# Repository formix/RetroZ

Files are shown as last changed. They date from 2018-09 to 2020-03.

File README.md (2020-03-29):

# RetroZ SBC S80
A minimalist single board Z80 retro computer based on the S80 design 
specifications.

This board is developped using the S80 physical specifications. The 
specifications are not currently available online but I plan to fix that in a 
future revision.

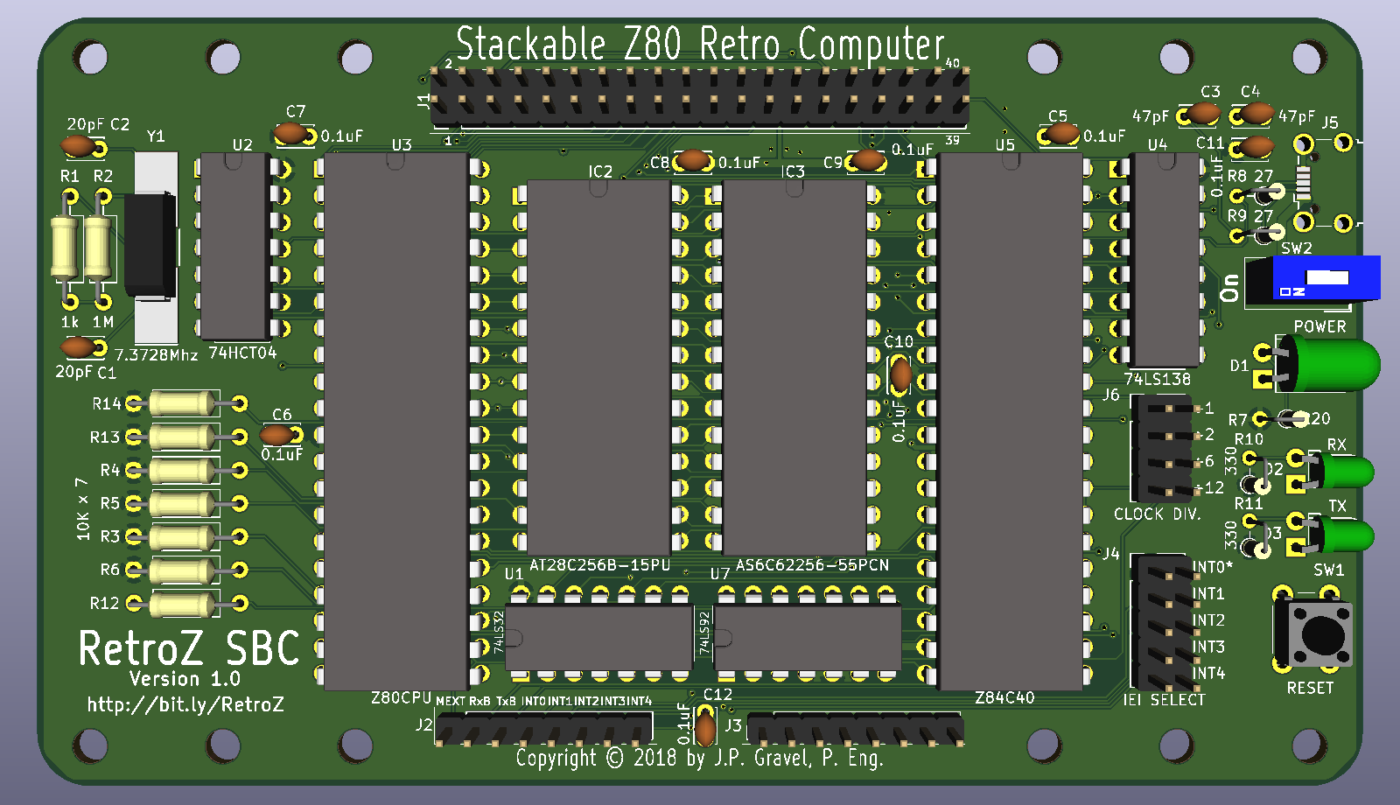
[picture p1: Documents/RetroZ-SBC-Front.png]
RetroZ SBC for S80 Architecture

*Front of the board*

[Back of the board](https://raw.githubusercontent.com/formix/RetroZ/master/Documents/RetroZ-SBC-Back.png)

You can find the board schematic as a PDF [here](https://github.com/formix/RetroZ/blob/master/Documents/RetroZ-SBC.pdf).

## BOM

You can download the BOM [here](https://github.com/formix/RetroZ/blob/master/Projects/RetroZ-SBC/RetroZ-SBC-BOM.ods?raw=true). It is an Open Document Worksheet file and you should be able to open it with Open/Libre Office or MS Excel. If you have issue, contact me.

| Comp. | Mouser#  | Digikey# | Mfr# | Qty | Description | 
|---|---|---|---|-----|---|
| C1,C2 | | | C317C200J5G5TA | 2 | 20pf Capacitor | 
| C3,C4 | | | FG28C0G1H470JNT06  | 2 | 47pF Capacitor | 
| C5,C6,C7,C8,C9,C10,C11,C12 | | | C322C104K5R5TA7301 | 8 | 0,1uF Capacitors | 
| D1 | | | 151051VS04000 | 1 | Green Led 5mm | 
| D2,D3 | | | 151031SS06000 | 2 | Red Led 3mm Round, FwdV 2.2 | 
| IC1 | | | ADM803TAKSZ-REEL7  | 1 | Power-on Reset chip | 
| IC2 | | | AT28C256-15PU | 1 | EEPROM 256kbit 28-Pin PDIP | 
| IC2,IC3 | | | 4828-6004-CP | 2 | CONN IC DIP SOCKET 28POS TIN | 
| IC3 | | | AS6C62256-55PCN | 1 | IC SRAM 256K PARALLEL 28DIP | 
| J1 | 485-2223 | 1528-1385-ND  | 2223 | 1 | Adafruit stacking header 2x20 | 
| J2,J3 | 485-85 | 1528-1074-ND  | 85 | 1 | STACKING HEADER ARDUINO SHIELD | 
| J4 | | | PRPC005DAAN-RC | 1 | 5x2 Pin Connector | 
| J4,J6 | | | QPC02SXGN-RC | 2 | 1x2 Shunt connector | 
| J5 | | | 629105150521 | 1 | USB Microb B SMT Connector | 
| J6 | | | PRPC004DAAN-RC | 1 | 4x2 Pin Connector | 
| R1 | | | RNF14FTD1M00 | 1 | 1M Ohm Resistor | 
| R10,R11 | | | RNF14FTD332R | 2 | 332 Ohm resistor | 
| R2 | | | RNF14FTD1K00 | 1 | 1k Ohm Resistor | 
| R3,R4,R5,R6,R12,R13,R14 | | | RNF14FTD10K0 | 7 | 10k Ohm Resistor | 
| R7 | | | RNF14FTD221R | 1 | 221 Ohm Resistor | 
| R8,R9 | | | RNF14FTD27R4 | 2 | 27 Ohm Resistors | 
| SW2 | | | BD01 | 1 | DIP Switch x1 | 
| U1 | | | 74LS32 | 1 | Quand OR | 
| U2 | | | 74HCT04 | 1 | Hex Inverter Schmidt Trigger | 
| U3 | | | Z84C0008PEG | 1 | Z80 CPU | 
| U3,U5 | | | 4840-6004-CP | 1 | 40 pin (2 x 20) DIP socket 15,24mm | 
| U4 | | | SN74LS138N | 1 | 3 to 8 Decoder/Demux | 
| U5 | | | Z84C4208PEG | 1 | Z80 SIO/2 | 
| U6 | | | FT230XS-U | 1 | UART to USB | 
| U7 | | | 74LS92 | 1 | Dodecade counter (div. By 12) | 
| Y1 | | | ECS-73-20-5PX-TR | 1 | 7,3728 MHz Crystal | 

## Development Note

### 2019-01-15
The review phase is done! I just sent the board to production. I should get the
finished board next week.

### 2019-01-26
I recieved my boards (10 boards!) yesterday. I just finished creating the BOM 
and sorted through my parts to order what is missing. I expect to recieve my 
order in the coming week. I'll work on the NASCOM Basic once I got the 
computer assembled. Stay tuned!

### 2019-08-03
It's been a while since I updated that README file but as you can see,
I'm committing regularily on the project. Simply put, I'm too busy playing 
with my working RetroZ SBC computer to update the front documentation. It is 
time to fix that, continue reading to get the full update.

## What's Inside?
The RetroZ-SBC computer is a 8MHz Z80 CPU clocked at 7.3728 MHz. It supports 
up to 32kB of ROM and 32kB of RAM. An SIO/2 chip is connected to the USB 
Micro B socket using an FTDI serial converter. Rx and Tx leds let you know 
when the computer communicates over USB. The whole computer is powered through
the same USB port and a power-on reset monitor resets the computer at startup.
A Reset button allows warm computer restart. An On/Off DIP switch controls the
power state of the computer and a power led indicator let you know that the 
beast is powered. All the Z80 processor pins are available through the 40 pins
stacking header plus some other on the User Port A. User Port B stacking
header is fully available (8 pins) for child boards future projects.

## The Connection
The USB to serial conversion is made possible thanks to an FTDI chip 
[behind the board](https://raw.githubusercontent.com/formix/RetroZ/master/Documents/RetroZ-SBC-Back.png) 
and is clocked at 115200 bauds by default. This speed can be changed 
programmatically through the Z84C40 (Zilog SIO/2) registers. On a Windows
machine the device can be accessed using **COM5**. For a 
Mac/Linux box it is **/dev/ttyUSB0**. Hardware flow control CTS/RTS is fully 
wired so feel free to flood the console with whatever you get, it should 
handle it.

## Technical Reference
### Power and commnunication over USB
Using a single USB Micro-B wire, it is possible to power-up and communicate 
with the computer. There is a DIP switch to set the computer on or off and a 
power indicator led indicates when the computer is powered on. There is also
a power line monitor chip (IC1) that pull the /RESET line LOW for 240 ms 
after power on.

### Serial Communication
Serial communication is achieved using a Z84C42 SIO/2 chip. The serial port A 
is connected to the USB jack through an FTDI UART to USB 2.0 converter. Rx 
and Tx leds indicate when communication occurs on that port. The serial port 
B is connected back into the User Port A (J2) PIN 2 (RxB) and Pin 3 (TxB) for 
slave cards serial communications.

**The serial port A clock** is directly tied to the clock and can be changed 
programmatically from the SIO/2 registers. In the NASCOM Basic provided, it is 
set to 115200 by default.

**The serial port B clock** The default speed is set to 115200 bauds as well. 
Again, that speed can be programmatically changed. The serial clock on port B 
goes through a dodecade counter and can be further adjusted using the 
`Clock div.` (J6) jumper that offers another set of 1,2,6 and 12 dividers. 
That gives a wide variety of standard baud rates down to 9600 bauds.

### Onboard memory control
The PIN 1 of the User Port A is pulled low with a 2k resistor. This is the 
on-board memory enable input pin (/ME). To disable onboard memory, an 
expansion card can set that pin HIGH. This would be the case with a memory 
expansion board. It can be hardwired to 5V to disable the onboard memory 
completely or it can be tied to some logic to leverage the on-board memory as 
needed.

### Interrupt Chaining
The RetroZ SBC design allows chaining interrupts of up to 4 slave boards. The
onboard SIO/2 IEO pin is hardwired to the User Port A INT0 (PIN 4). Its 
Interrupt Enable In pin can be tied to any of the other INT pins using the 
IEI Select jumper (J4). Selecting the first position of that jumper (INT0) 
sets the on-board SIO/2 as the Master. On slave boards, the Interrupt Enable 
In will have 6 positions. Also, a 4 positions IEO jumper header should be 
provided to select the right User Port A IEO position (pins 5-8). More on 
that on the slave board design document.

**WARNING** User Port A pins 4-8 (interrupts) are not protected. If you 
connect a daughter board without checking jumper settings first, you could 
short an IO pin on your stack and damage a chip! Looking into a solution to 
that in a future revision.

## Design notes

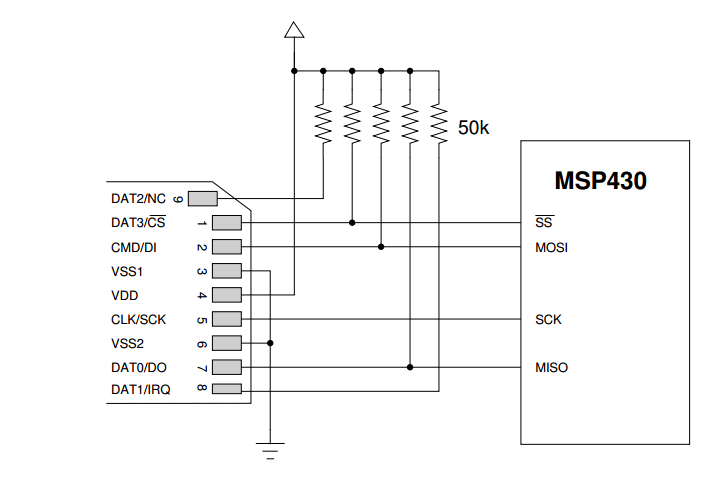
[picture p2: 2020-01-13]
Projects/RetroZ-disk/external-content.duckduckgo.com.png

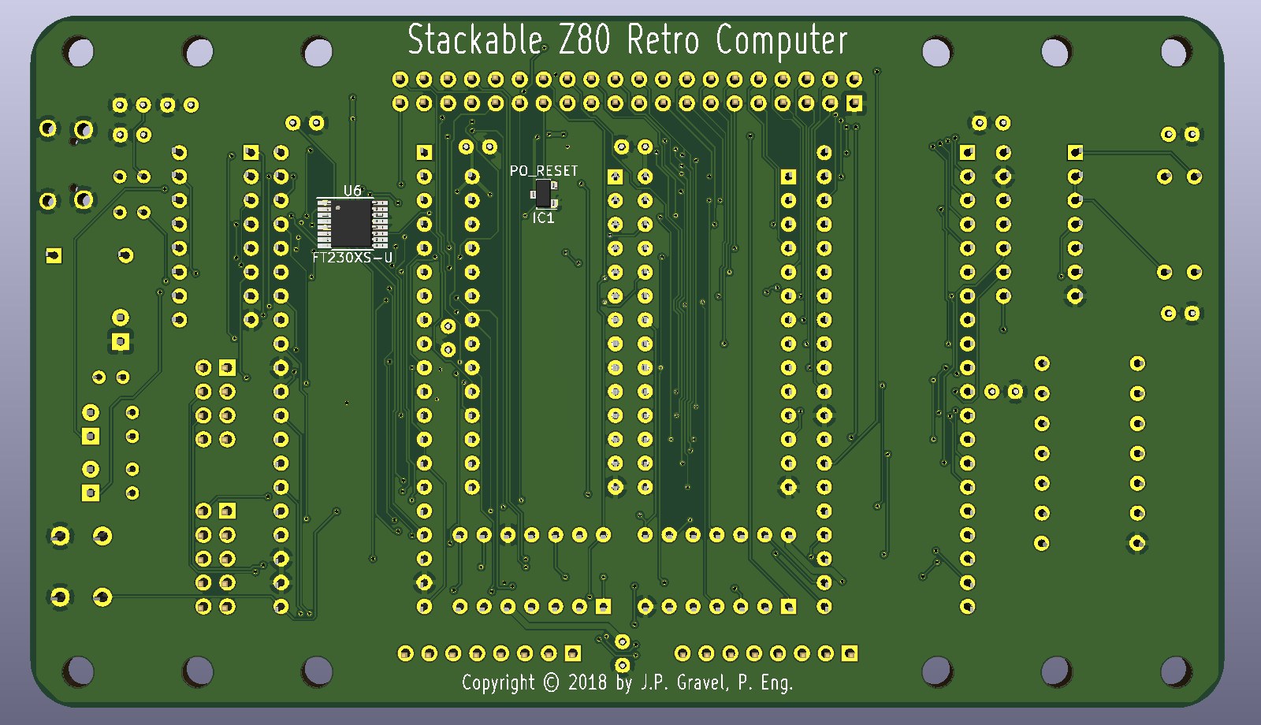
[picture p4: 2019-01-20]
Documents/RetroZ-SBC-Back.png

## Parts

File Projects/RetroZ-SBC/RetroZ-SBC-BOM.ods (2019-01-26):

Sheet: BOM
Comp. | Mouser# | Digikey# | Mfr# | Qty | Description | In stock | Mfr# | Order
C1,C2 |  |  | C317C200J5G5TA | 2 | 20pf Capacitor | 2 | C317C200J5G5TA | 0
C3,C4 |  |  | FG28C0G1H470JNT06 | 2 | 47pF Capacitor | 2 | FG28C0G1H470JNT06 | 0
C5,C6,C7,C8,C9,C10,C11,C12 |  |  | C322C104K5R5TA7301 | 8 | 0,1uF Capacitors | 0 | C322C104K5R5TA7301 | 8
D1 |  |  | 151051VS04000 | 1 | Green Led 5mm | 1 | 151051VS04000 | 0
D2,D3 |  |  | 151031SS06000 | 2 | Red Led 3mm Round, FwdV 2.2 | 2 | 151031SS06000 | 0
IC1 |  |  | ADM803TAKSZ-REEL7 | 1 | Power-on Reset chip | 1 | ADM803TAKSZ-REEL7 | 0
IC2 |  |  | AT28C256-15PU | 1 | EEPROM 256kbit 28-Pin PDIP | 0 | AT28C256-15PU | 1
IC2,IC3 |  |  | 4828-6004-CP | 2 | CONN IC DIP SOCKET 28POS TIN | 2 | 4828-6004-CP | 0
IC3 |  |  | AS6C62256-55PCN | 1 | IC SRAM 256K PARALLEL 28DIP | 0 | AS6C62256-55PCN | 1
J1 | 485-2223 | 1528-1385-ND | 2223 | 1 | Adafruit stacking header 2x20 | 1 | 1528-1385-ND | 0
J2,J3 | 485-85 | 1528-1074-ND | 85 | 1 | STACKING HEADER ARDUINO SHIELD | 0 | 1528-1074-ND | 1
J4 |  |  | PRPC005DAAN-RC | 1 | 5x2 Pin Connector | 0 | PRPC005DAAN-RC | 1
J4,J6 |  |  | QPC02SXGN-RC | 2 | 1x2 Shunt connector | 0 | QPC02SXGN-RC | 2
J5 |  |  | 629105150521 | 1 | USB Microb B SMT Connector | 1 | 629105150521 | 0
J6 |  |  | PRPC004DAAN-RC | 1 | 4x2 Pin Connector | 0 | PRPC004DAAN-RC | 1
R1 |  |  | RNF14FTD1M00 | 1 | 1M Ohm Resistor | 1 | RNF14FTD1M00 | 0
R10,R11 |  |  | RNF14FTD332R | 2 | 332 Ohm resistor | 0 | RNF14FTD332R | 2
R2 |  |  | RNF14FTD1K00 | 1 | 1k Ohm Resistor | 1 | RNF14FTD1K00 | 0
R3,R4,R5,R6,R12,R13,R14 |  |  | RNF14FTD10K0 | 7 | 10k Ohm Resistor | 7 | RNF14FTD10K0 | 0
R7 |  |  | RNF14FTD221R | 1 | 221 Ohm Resistor | 0 | RNF14FTD221R | 1
R8,R9 |  |  | RNF14FTD27R4 | 2 | 27 Ohm Resistors | 0 | RNF14FTD27R4 | 2
SW2 |  |  | BD01 | 1 | DIP Switch x1 | 1 | BD01 | 0
U1 |  |  | 74LS32 | 1 | Quand OR | 1 | 74LS32 | 0
U2 |  |  | 74HCT04 | 1 | Hex Inverter Schmidt Trigger | 1 | 74HCT04 | 0
U3 |  |  | Z84C0008PEG | 1 | Z80 CPU | 1 | Z84C0008PEG | 0
U3,U5 |  |  | 4840-6004-CP | 1 | 40 pin (2 x 20) DIP socket 15,24mm | 1 | 4840-6004-CP | 0
U4 |  |  | SN74LS138N | 1 | 3 to 8 Decoder/Demux | 1 | SN74LS138N | 0
U5 |  |  | Z84C4208PEG | 1 | Z80 SIO/2 | 1 | Z84C4208PEG | 0
U6 |  |  | FT230XS-U | 1 | UART to USB | 1 | FT230XS-U | 0
U7 |  |  | 74LS92 | 1 | Dodecade counter (div. By 12) | 1 | 74LS92 | 0
Y1 |  |  | ECS-73-20-5PX-TR | 1 | 7,3728 MHz Crystal | 1 | ECS-73-20-5PX-TR | 0

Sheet: Order
Mfr# | Order
RNF14FTD1M00 | 0
RNF14FTD1K00 | 0
74HCT04 | 0
ECS-73-20-5PX-TR | 0
C317C200J5G5TA | 0
ADM803TAKSZ-REEL7 | 0
FT230XS-U | 0
BD01 | 0
629105150521 | 0
RNF14FTD27R4 | 2 | 2,RNF14FTD27R4,
FG28C0G1H470JNT06 | 0
C322C104K5R5TA7301 | 8 | 8,C322C104K5R5TA7301,
151031SS06000 | 0
RNF14FTD332R | 2 | 2,RNF14FTD332R,
RNF14FTD10K0 | 0
74LS32 | 0
RNF14FTD221R | 1 | 1,RNF14FTD221R,
151051VS04000 | 0
74LS92 | 0
SN74LS138N | 0
PRPC004DAAN-RC | 1 | 1,PRPC004DAAN-RC,
PRPC005DAAN-RC | 1 | 1,PRPC005DAAN-RC,
QPC02SXGN-RC | 2 | 2,QPC02SXGN-RC,
1528-1385-ND | 0
1528-1074-ND | 1 | 1,1528-1074-ND,
Z84C0008PEG | 0
4840-6004-CP | 0
Z84C4208PEG | 0
AT28C256-15PU | 1 | 1,AT28C256-15PU,
AS6C62256-55PCN | 1 | 1,AS6C62256-55PCN,
4828-6004-CP | 0

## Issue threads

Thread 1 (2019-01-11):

General questions on design 2018-12-26

ghost, 2019-01-11:
Hi @formix,

First of all: _**great job**_! I like the schematic and the PCB even more. It's great that u use the Z80 SIO IC and that you join the schematics for UART to USB. The way you integrate your RetroZ with possible S80 extension cards is _**very well done and to my opinion flawless**_!

However, I have some minor questions.

# Schematics

### 1. Pull-down resistors

You don't pull down the -BusRq- pin of the CPU. Is there a special reason to keep it floating? I'm attentive to this element, since it's my major mistake on the design of the cpu board of the S80 Version 2.0 :-)

### 2. -Reset-

I'm a bit puzzled on the -Reset- circuit. The switch pulls it down to Gnd when pushed, and the resistor pulls it up by default. However, I don't see what IC1 is doing.

Is there a chance that your button will bounce and disturb the reset process of your RetroZ?

### 3. MEM_EXT

Please ignore my remark on pulling down the MEM_EXT pin in the S80 issue u've opened. You already do so (which I missed at my first reading of your schematics). Sorry for that.

### 4. SIO2_SEL generation

If I'm not mistaking, by using the 74xx138, you reserve all addresses of the format 111001xx (base address 0xE4). Is that correct?

### 5. USB

I'm I correct that you don't implement the UART to USB on your PCB?

# PCB

Is there a reason why u use males for the 2x20 connector on the top side of your PCB? The S80 uses the female side of the connectors on the top side and male connectors on the bottom side.

# Documentation on GitHub

I like your documentation very much. It's clear, extensive, and complete. If you ever feel the urge to document the S80 repository in the same way, please do not hesitate.

# Proposal

If you like, I can put your RetroZ-SBC repository (or a copy of the final version, the files that you choose) as a third party made S80 CPU/SERIAL/MEMORY card in a subdirectory of the S80/hardware. e.g. S80/Hardware/RetroZ-SBC. This can include documentation, libraries, your name and copyright notices, ...

Once you have software for your RetroZ, I can also put versions of your software in the S80/Software directory.

I like to copy in stead of linking, since that way, I prevent having dead links in the future, and I'm sure to have a stable version to distribute to the public.

# On the whole

Splendid job, respect !

formix, 2019-01-11:
Hi @PaintedBlck ,

First I'd like to thank you for taking some time to review my work, It is really appreciated!

So here are my asnwers:

#A: 1. Pull-down resistors
I totally forgot that one, thanks! But you mean a **pull-up** resistor right? based on the [RC2014 mini schematics](http://rc2014.co.uk/wp-content/uploads/2016/10/RC2014-Mini.pdf), I think both ~BUSREQ and ~BUSACK shall be pulled high. I'll fix that!

#A: 2. Reset
When [IC1](https://www.mouser.ca/ProductDetail/584-ADM803TAKSZ-R7) is powered, it pulls its PIN 2 LOW for 240ms then keep it HIGH. That's it. It is a power-on reset chip that saves a lot of space and some components. On the schematic, it is located left of the processor and it is connected on the bus. I think it would help to have it near the reset button and add some text next to it to make things clearer.

#A: 3. MEM_EXT
Ok, no issue then :).

#A: 4. SIO2_SEL generation
No, given the way the 74xx138 chip is connected, the reserved addresses are 0x00 to 0x03.

#A: 5. USB
The UART to USB is fully connected and working, based on my previous tests. The FT230XS chip is doing its magic and makes the board plung and play. Note that a USB port marked with a lightning should be used since these ports can deliver more amps (these are charger ports on the computer).

#A: PCB
Yeah, my note under the board's 3D view is wrong, I should have said TOP instead of BOTTOM. I'll fix that.

#A: Documentation on GitHub
Yeah, I'd be pleased to do that. I'll see where I can start and try to fit that in my schedule.

#A: Proposal
That would make sense but I'm still planning to change a few things before I send my board to production. You can do as you wish but I already plan to keep the repos open and images and PDFs where they are since that would break my documentation as well! I'll let you know when I update my things.

Thanks angain for your good words adn comments!

Closed 2019-09-08.

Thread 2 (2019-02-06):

The clock signal oscillate between 3v and 5v

formix, 2019-02-06:
Instead of oscillating between 0 and 5 vols, it oscillates between 3 and 5v. Nothing works with that.

formix, 2019-02-06:
After reviewing the board drawings, I saw that I inverted the 1M and 1K resistor label! I'llahave to replace the resistors and test again but I'm pretty sure it will be good.

formix, 2019-02-09:
Fixed, that was the issue!

Closed 2019-02-09.

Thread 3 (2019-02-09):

Unable to wake-up the SIO/2 chip

formix, 2019-02-09:
Hi all,

I need some help regarding my board. I'm not able to make the SIO/2 chip work. There is a chance that there is some physical issues I guess but I spent 3 months reviewing with some help from other people. For now, I would like to tackle this issues from the software angle.

First to make a quick and dirty 8k ROM, I slapped together Dr Scott M. Baker's ASM files for [SIO initialization](https://github.com/formix/rc2014/blob/master/asm/intsio.asm) and [8k Basic](https://github.com/formix/rc2014/blob/master/basic_work/scbasic/basdisk.asm). I fixed a few labels and changed SIOA_C, SIOA_D, SIOB_C and SIOB_D values to fit with my architecture (0x00, 0x01, 0x02 and 0x03 respectively). See my mashed-up file [here](https://github.com/formix/RetroZ/blob/master/asm/basic/sio_basic_32k.asm).

I expected that to be working but it's not doing anything. To make sure its is not related to my FTDI chip, I removed the SIO/2 chip and connected TX and RX together. The RX and TX leds are flashing with each letter I'm typing and I can see the "echo" in my terminal window.

I spent maybe two hours analyzing the SIO and BASIC asm code but I must admit that I'm still lost. I did slap the two files together within my [ASM source file](https://github.com/formix/RetroZ/blob/master/asm/basic/sio_basic_32k.asm) but it is basically what another shell script from @sbelectronics did (I can't find it anymore though). The `JP $0290` at the end of the first script and the `.ORG $0290` at the beginig of the second comforted me that It was ok like that. Other than a few lost clock cycles, I don't think that the CTC initialization stuff has anything to do with my issue.

I'm working in Ubuntu Bash with zasm.

One strange thing is that the generated ROM file has its instructions and operands inverted. For example, If I create an ASM file containing the following code:

```asm
  .ORG $0000
  LD A, 0
  .END
```
I'm expecting to see `3e00` (3e = `LD A`; 00 => the value `00`) in the resulting ROM file.

But what I see in the hexdump is this:
```hex
0000000 003e                           
0000002
```
The operand and the instruction are inverted!!! I was expecting to see big-endianess for 16 bits operands but not a flipped instruction! Why are the instruction and operand inverted? Is it an issue? Any idea what might be the overall problem here?

PaintedBlck, 2019-02-10:
To my knowledge, the Z80 is a big-ender, meaning that a 2-byte word (goes for instructions to) inverts its bytes to store them in memory (the same as the Intel 80x86 series do). So your hexdump is correct, since Zasm (and others) make a ROM that is 100% RAM compatible (immediately executable). Just storing things in it won't work.

On the other problem: have you tried to measure the pins of the SIO/2 with a logic analyser (I can advise e.g. the Kingst Logic Analyzer which does the trick for me). That way, you can measure some Z80 pins, some SIO/2 pins and see if the signals that have to arrive at the SIO/2 effectively arrive.

Grtz,
Filip

formix, 2019-02-11:
Thanks for your inputs @PaintedBlck!

You are right, I shall get back to the basics and make things simple. I tried to follow that path at first but I quickly switched to the "slap things together" when I found Dr S.M. Baker's code.

I do not have a logic analyzer, in fact I did not know that these things existed at all before you mentionned it. I was crudely debugging using a voltmeter and a barely working analog oscilloscope from the sixties.

I'll do what you suggest and update on my progress here.

formix, 2019-02-14:
I found out! I found out!!!!

The resistor R12 is a pull down.  but for some reason, the reading on it was around 1.9V instead of 0. This line being connected to the OR gate pin 2 to deactivate the RAM and ROM chips if the S80 "M/4M memory expansion board is present (it is also connected on the User port A, PIN 1).

**That 1.9V value is enough to turn the 74LS32N to HIGH, thus disabling the ROM's ~CE line!!!**

To check if I was right, I jumped that resistor and Bingo, I started to see the TX led flash like crazy and my terminal window being filled with X characters at the tremedeous speed of 115kb!!!!

The fix is to remove that resistor for now and jump it directly with a wire. I will double check but there is a good chance that changing that LS chip for an HCT will do the trick!!!

Man it feels great, that was my first hardware debugging!!!

Big thanks to @PaintedBlck  for you support and wisdom (I ordered a Kingst digital analyzer just yesterday) and to **Sylvain Beauregard**  for his good old oscilloscope!

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

Closed 2019-02-14.

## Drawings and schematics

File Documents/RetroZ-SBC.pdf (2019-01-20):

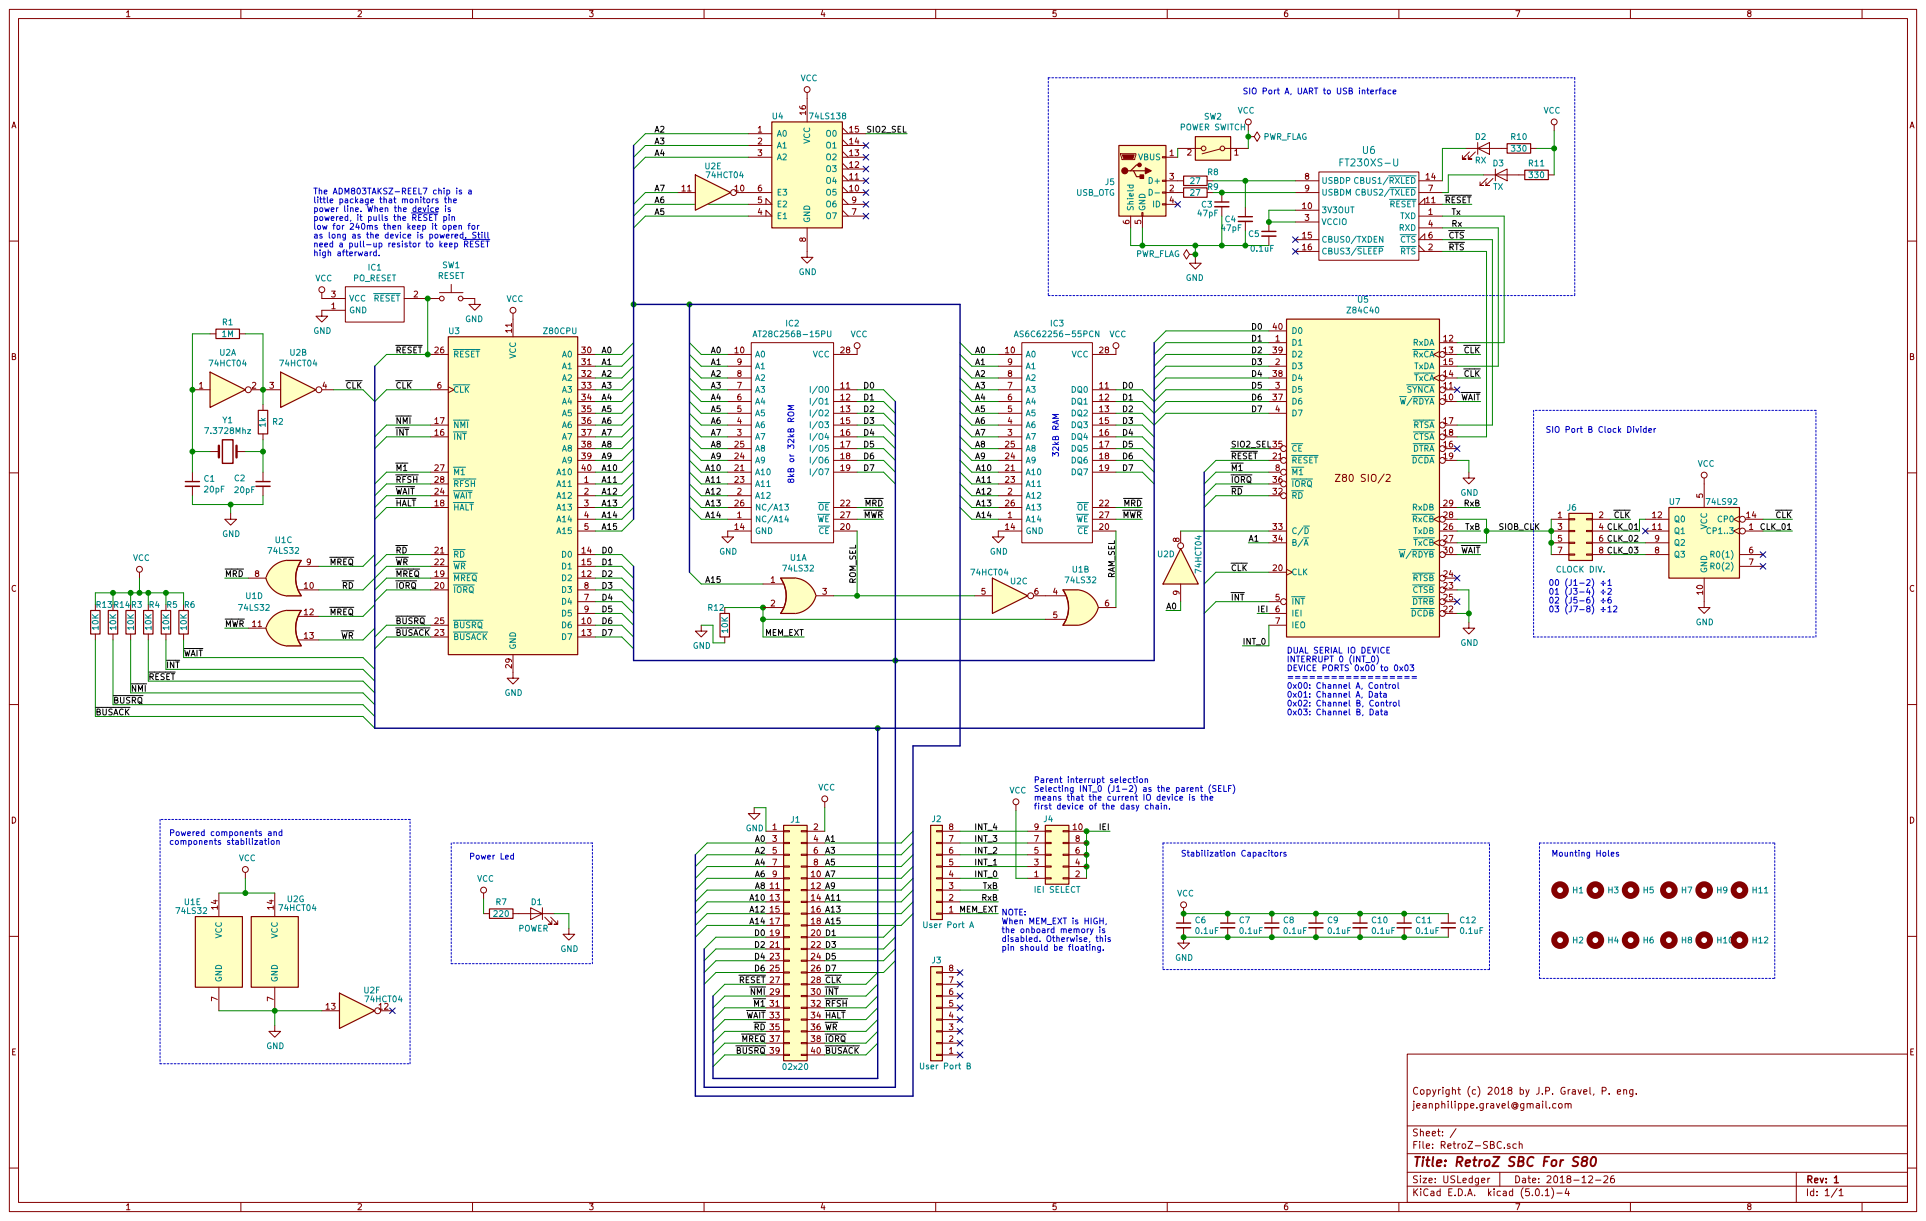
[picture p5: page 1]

The ADM803TAKSZ-REEL7 chip is a
little package that monitors the
power line. When the device is
powered, it pulls the RESET pin
low for 240ms then keep it open for
as long as the device is powered. Still
need a pull-up resistor to keep RESET

INT A1 A0 NMI HALT BUSRQ

INT M1 WAIT RDWR MREQ
BUSACK RFSH

INTERRUPT 0 (INT_0) DEVICE PORTS 0x00 to 0x03 ==================

0x00: Channel A, Control 0x01: Channel A, Data
0x02: Channel B, Control 0x03: Channel B, Data

Selecting INT_0 (J1-2) as the parent (SELF) means that the current IO device is the
first device of the dasy chain. 1

NOTE: When MEM_EXT is HIGH,
the onboard memory is disabled. Otherwise, this pin should be floating.

Copyright (c) 2018 by J.P. Gravel, P. eng.
jeanphilippe.gravel@gmail.com

File: RetroZ-SBC.sch Sheet: /
Id: 1/1 Title: RetroZ SBC For S80

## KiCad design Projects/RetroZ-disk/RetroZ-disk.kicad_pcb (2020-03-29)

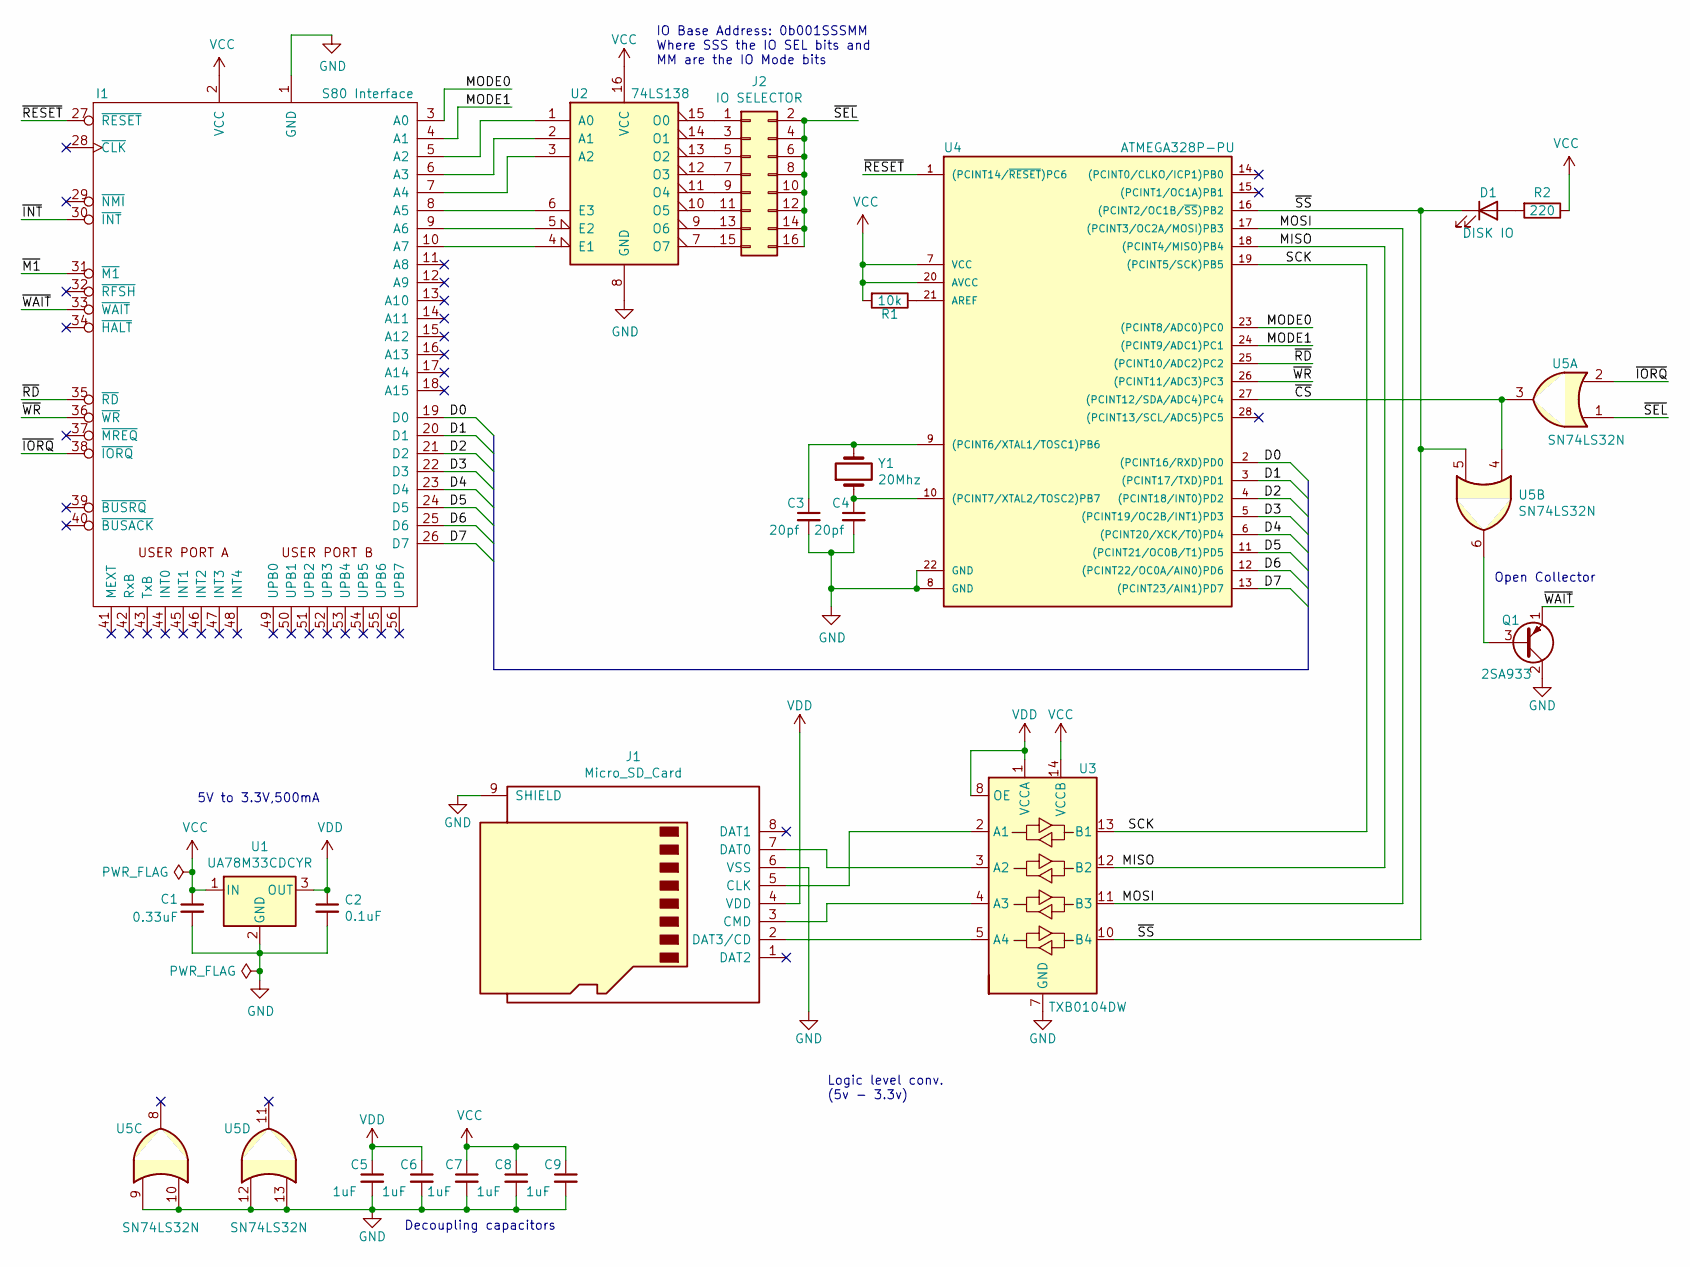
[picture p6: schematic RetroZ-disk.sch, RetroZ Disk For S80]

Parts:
C1: 0.33uF; R_1206_HandSoldering; Mfr# 1206B334K500CT
C2: 0.1uF; R_1206_HandSoldering; Mfr# C1206C104K5RAC7210
C3, C4: 20pf; R_1206_HandSoldering; Mfr# C1206C200K5GACTU
C5, C6, C7, C8, C9: 1uF; R_1206_HandSoldering; Mfr# SH31B105K500CT
D1: DISK IO; LED_D5.0mm_Horizontal_O1.27mm_Z3.0mm; Mfr# NL-5AR30
I1: S80 Interface; S80-1
J1: Micro_SD_Card; MicroSd_Wurth_693072010801; Mfr# 693072010801
J2: IO SELECTOR; Pin_Header_Straight_2x08_Pitch2.54mm; Mfr# 87914-1616
Q1: 2SA933; TO-92S_Wide
R1: 10k; R_1206_HandSoldering; Mfr# CRCW120610K0FKEAC
R2: 220; R_1206_HandSoldering; Mfr# CRCW1206220RFKEAC
U1: UA78M33CDCYR; SOT-223-3_TabPin2
U2: 74LS138; DIP-16_W7.62mm_LongPads; Mfr# SN74HC138N
U3: TXB0104DW; SOIC-14_3.9x8.7mm_P1.27mm
U4: ATMEGA328P-PU; DIP-28_W7.62mm_LongPads
U5: SN74LS32N; DIP-14_W7.62mm_LongPads
Y1: 20Mhz; Crystal_HC49-4H_Vertical

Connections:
/D0: I1.19 (D0), U4.2 ((PCINT16/RXD)PD0)
/D1: I1.20 (D1), U4.3 ((PCINT17/TXD)PD1)
/D2: I1.21 (D2), U4.4 ((PCINT18/INT0)PD2)
/D3: I1.22 (D3), U4.5 ((PCINT19/OC2B/INT1)PD3)
/D4: I1.23 (D4), U4.6 ((PCINT20/XCK/T0)PD4)
/D5: I1.24 (D5), U4.11 ((PCINT21/OC0B/T1)PD5)
/D6: I1.25 (D6), U4.12 ((PCINT22/OC0A/AIN0)PD6)
/D7: I1.26 (D7), U4.13 ((PCINT23/AIN1)PD7)
/MISO: U3.12 (B2), U4.18 ((PCINT4/MISO)PB4)
/MODE0: I1.3 (A0), U4.23 ((PCINT8/ADC0)PC0)
/MODE1: I1.4 (A1), U4.24 ((PCINT9/ADC1)PC1)
/MOSI: U3.11 (B3), U4.17 ((PCINT3/OC2A/MOSI)PB3)
/SCK: U3.13 (B1), U4.19 ((PCINT5/SCK)PB5)
/~CS: U4.27 ((PCINT12/SDA/ADC4)PC4), U5.3, U5.4
/~INT: I1.30 (~INT~)
/~IORQ: I1.38 (~IORQ~), U5.2
/~M1: I1.31 (~M1~)
/~RD: I1.35 (~RD~), U4.25 ((PCINT10/ADC2)PC2)
/~RESET: I1.27 (~RESET~), U4.1 ((PCINT14/~RESET~)PC6)
/~SEL: J2.2, J2.4, J2.6, J2.8, J2.10, J2.12, J2.14, J2.16, U5.1
/~SS: D1.1 (K), U3.10 (B4), U4.16 ((PCINT2/OC1B/~SS~)PB2), U5.5
/~WAIT: I1.33 (~WAIT~), Q1.1 (E)
/~WR: I1.36 (~WR~), U4.26 ((PCINT11/ADC3)PC3)
GND: C1.2, C2.2, C3.2, C4.2, C5.2, C6.2, C7.2, C8.2, C9.2, I1.1 (GND), J1.6 (VSS), J1.9 (SHIELD), Q1.2 (C), U1.2 (GND), U2.8 (GND), U3.7 (GND), U4.8 (GND), U4.22 (GND), U5.9, U5.10, U5.12, U5.13
unnamed: C3.1, U4.9 ((PCINT6/XTAL1/TOSC1)PB6), Y1.2
unnamed: C4.1, U4.10 ((PCINT7/XTAL2/TOSC2)PB7), Y1.1
unnamed: D1.2 (A), R2.2
unnamed: I1.5 (A2), U2.1 (A0)
unnamed: I1.6 (A3), U2.2 (A1)
unnamed: I1.7 (A4), U2.3 (A2)
unnamed: I1.8 (A5), U2.6 (E3)
unnamed: I1.9 (A6), U2.5 (E2)
unnamed: I1.10 (A7), U2.4 (E1)
unnamed: J1.2 (DAT3/CD), U3.5 (A4)
unnamed: J1.3 (CMD), U3.4 (A3)
unnamed: J1.5 (CLK), U3.2 (A1)
unnamed: J1.7 (DAT0), U3.3 (A2)
unnamed: J2.1, U2.15 (O0)
unnamed: J2.3, U2.14 (O1)
unnamed: J2.5, U2.13 (O2)
unnamed: J2.7, U2.12 (O3)
unnamed: J2.9, U2.11 (O4)
unnamed: J2.11, U2.10 (O5)
unnamed: J2.13, U2.9 (O6)
unnamed: J2.15, U2.7 (O7)
unnamed: Q1.3 (B), U5.6
unnamed: R1.1, U4.21 (AREF)
VCC: C1.1, C7.1, C8.1, C9.1, I1.2 (VCC), R1.2, R2.1, U1.1 (IN), U2.16 (VCC), U3.14 (VCCB), U4.7 (VCC), U4.20 (AVCC)
VDD: C2.1, C5.1, C6.1, J1.4 (VDD), U1.3 (OUT), U3.1 (VCCA), U3.8 (OE)

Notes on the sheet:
Logic level conv. (5v - 3.3v)
5V to 3.3V,500mA
IO Base Address: 0b001SSSMM Where SSS the IO SEL bits and MM are the IO Mode bits
Decoupling capacitors
Open Collector

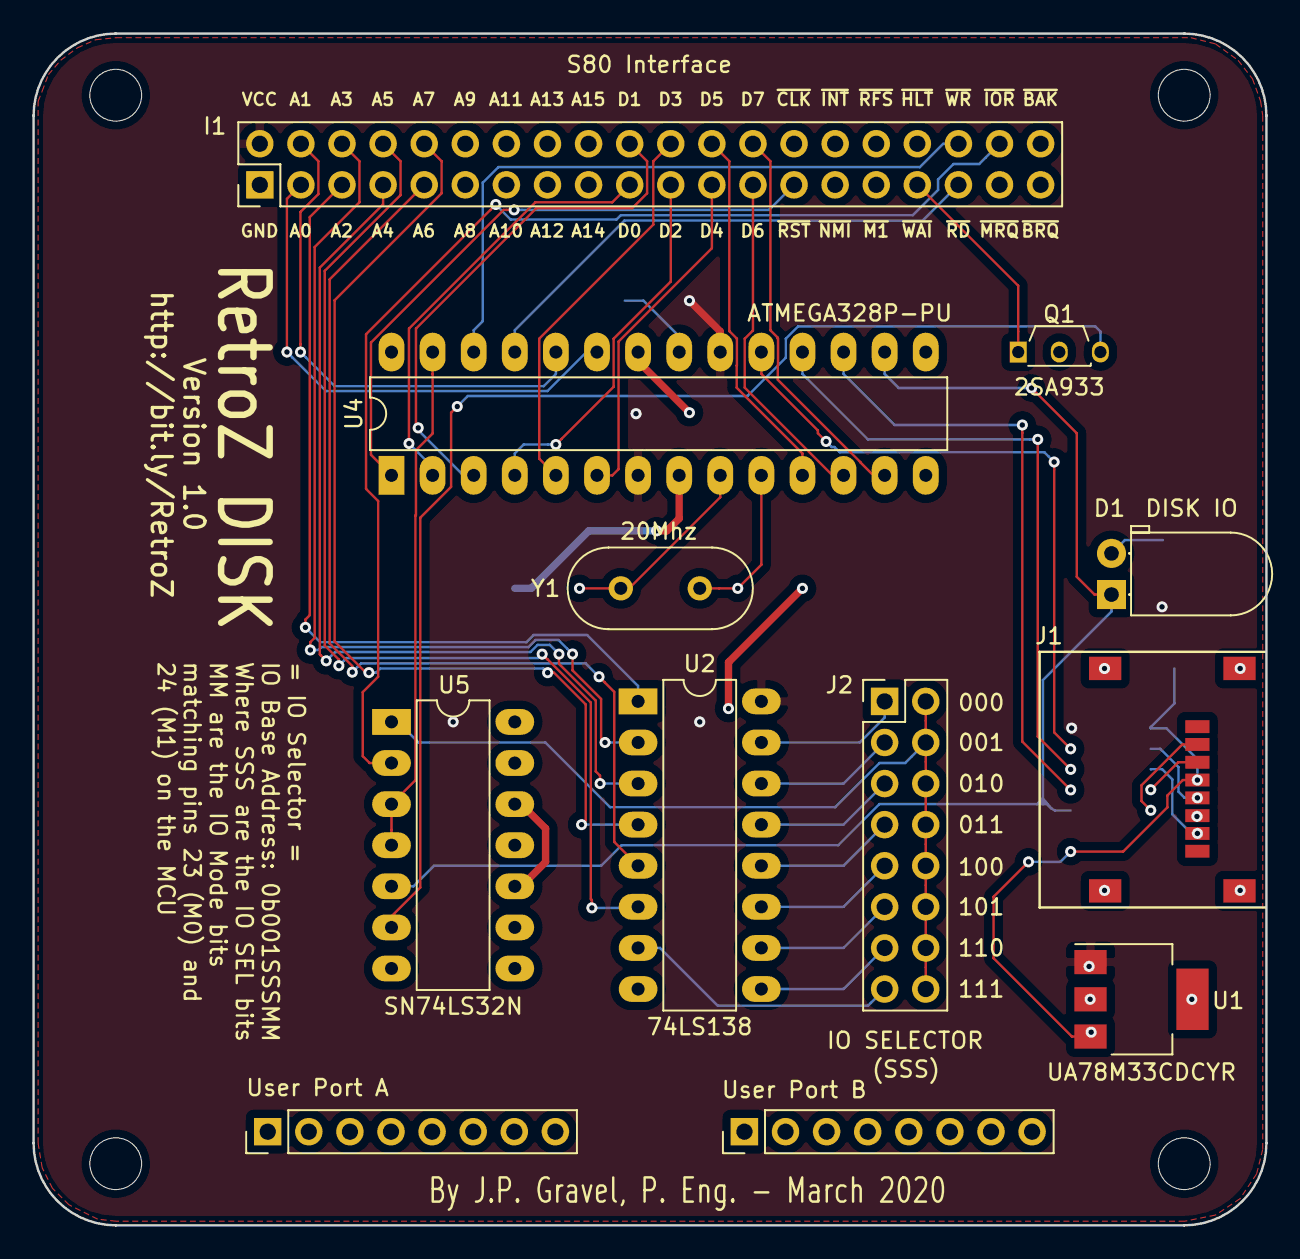
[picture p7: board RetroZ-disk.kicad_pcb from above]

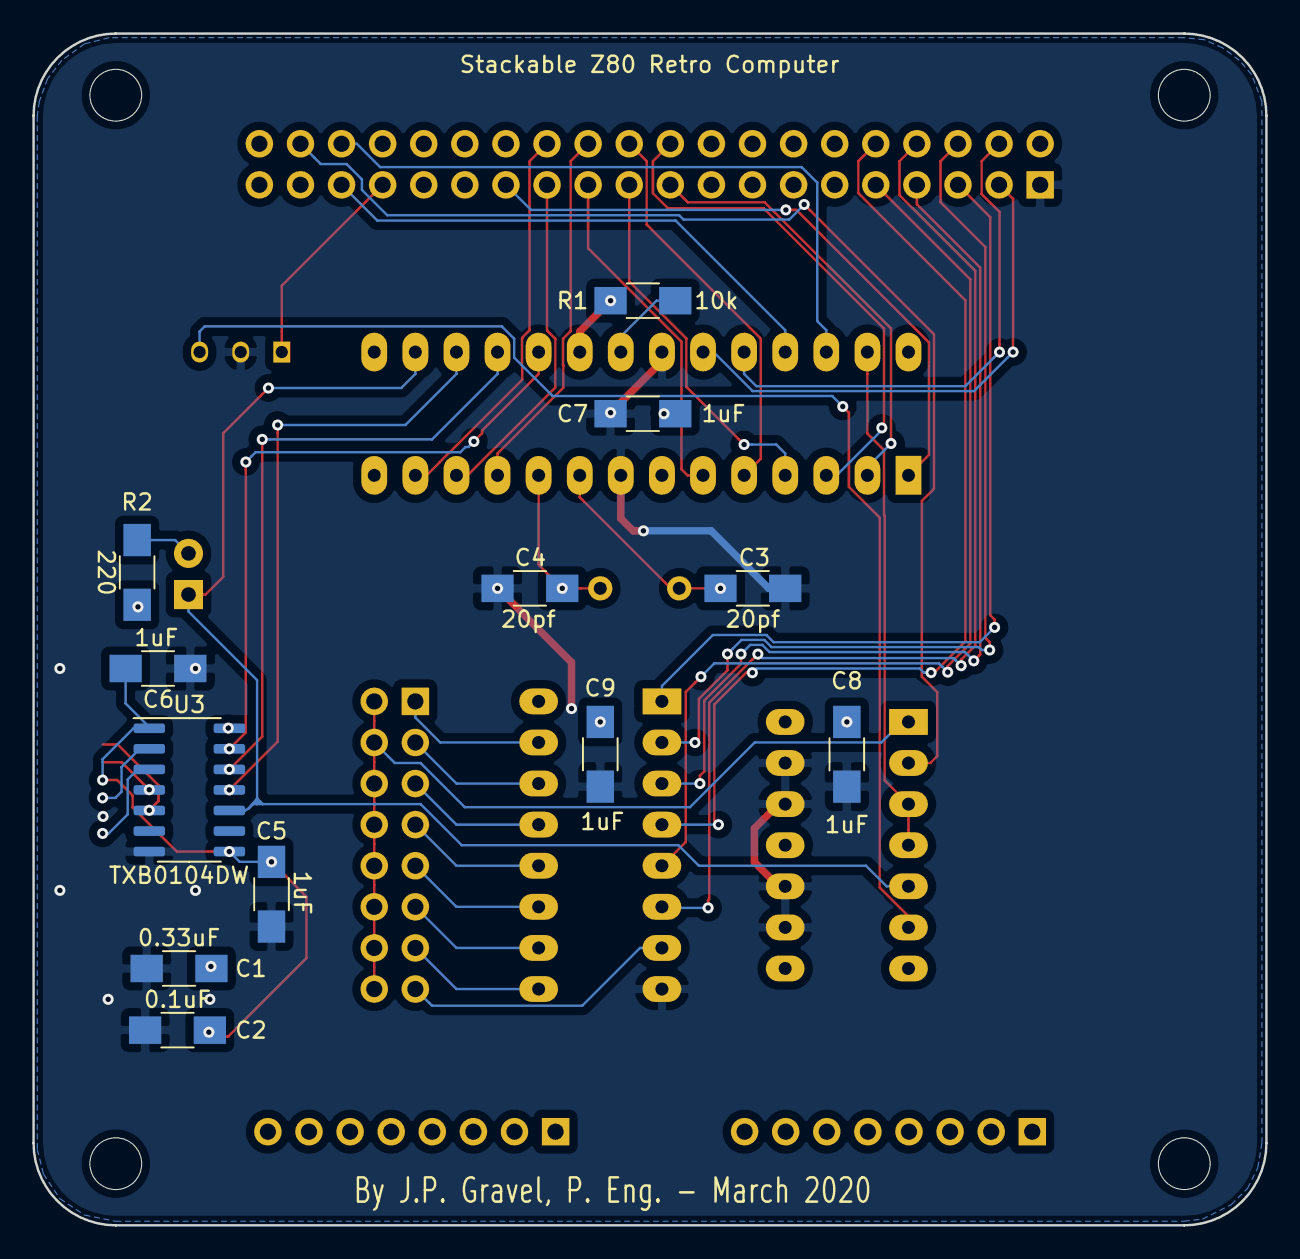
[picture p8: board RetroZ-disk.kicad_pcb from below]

Board: 2 copper layers, 76.2 x 73.7 mm, 22 parts (12 on the bottom side), 47 nets.

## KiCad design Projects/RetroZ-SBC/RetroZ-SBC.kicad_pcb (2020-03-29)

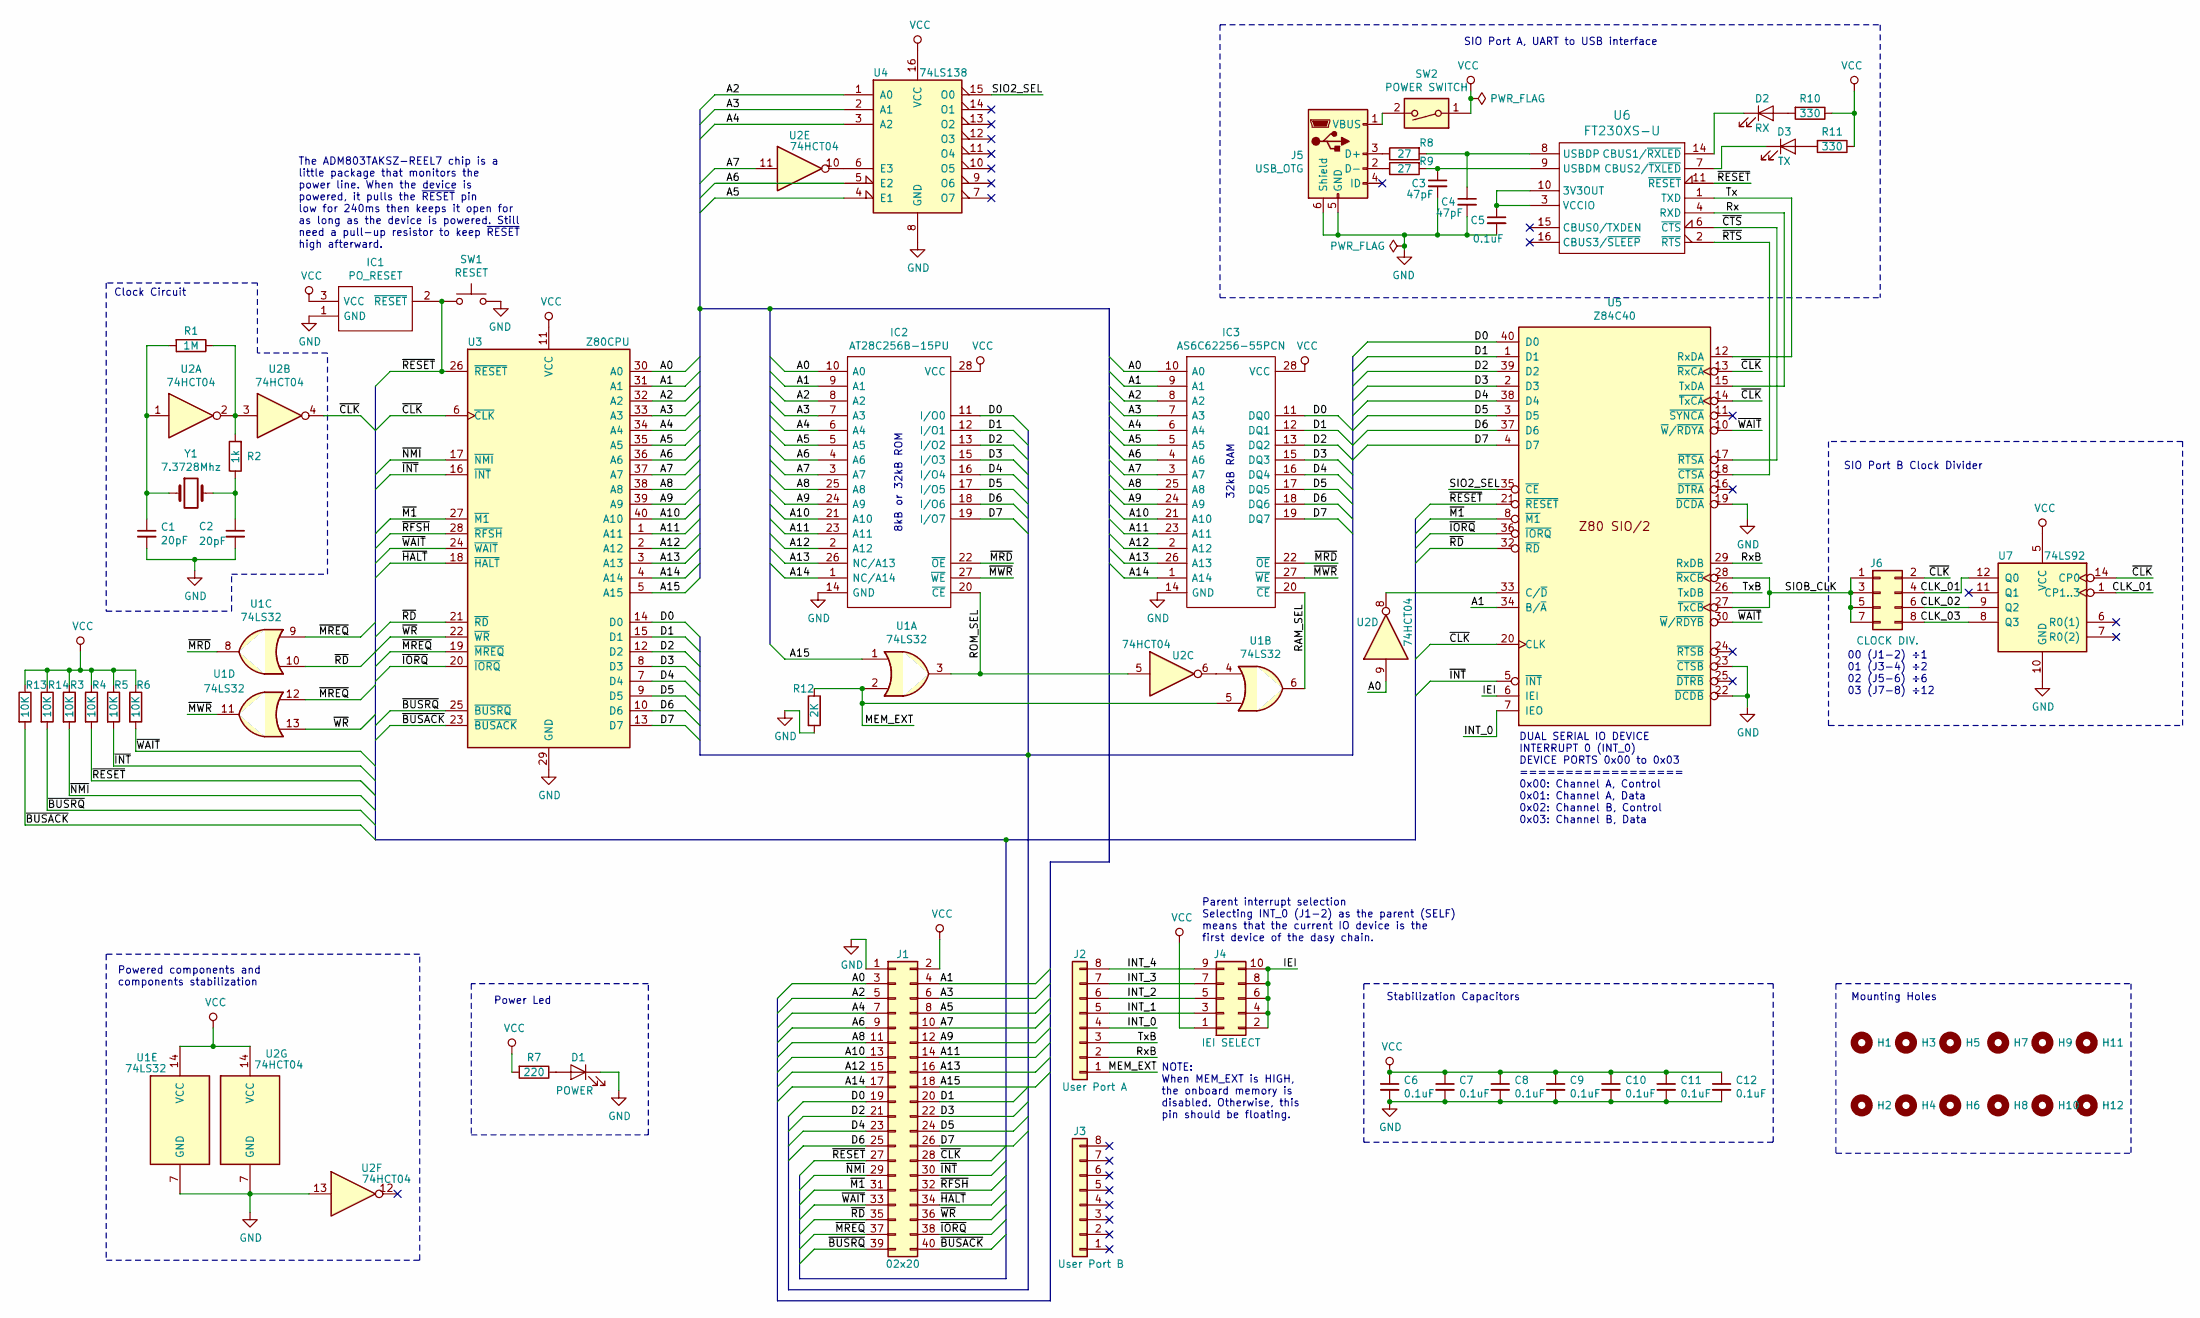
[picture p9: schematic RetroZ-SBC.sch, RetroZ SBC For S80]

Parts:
C1, C2: 20pF; C_Disc_D3.4mm_W2.1mm_P2.50mm; Mfr# C317C200J5G5TA
C3, C4: 47pF; C_Disc_D3.4mm_W2.1mm_P2.50mm; Mfr# FG28C0G1H470JNT06
C5, C6, C7, C8, C9, C10, C11, C12: 0.1uF; C_Disc_D3.4mm_W2.1mm_P2.50mm; Mfr# C322C104K5R5TA7301
D1: POWER; LED_D5.0mm_Horizontal_O1.27mm_Z3.0mm; Mfr# 151051VS04000
D2: RX; LED_D3.0mm_Horizontal_O1.27mm_Z2.0mm; Mfr# 151031SS06000
D3: TX; LED_D3.0mm_Horizontal_O1.27mm_Z2.0mm; Mfr# 151031SS06000
H1, H2, H3, H4, H5, H6, H7, H8, H9, H10, H11, H12: MountingHole; MountingHole_3.2mm_M3
IC1: PO_RESET; SOT-23; Mfr# ADM803TAKSZ-REEL7
IC2: AT28C256B-15PU; DIP-28_W15.24mm; Mouser Part Number 556-AT28C25615PU
IC3: AS6C62256-55PCN; DIP-28_W15.24mm; Mouser Part Number 913-AS6C62256-55PCN
J1: 02x20; Pin_Header_Straight_2x20_Pitch2.54mm; Mfr# 2223
J2: User Port A; Pin_Header_Straight_1x08_Pitch2.54mm
J3: User Port B; Pin_Header_Straight_1x08_Pitch2.54mm
J4: IEI SELECT; Pin_Header_Straight_2x05_Pitch2.54mm; Mfr# PRPC005DAAN-RC
J5: USB_OTG; USB_Micro-B_Wuerth-629105150521_CircularHoles; Mfr# 629105150521
J6: CLOCK DIV.; Pin_Header_Straight_2x04_Pitch2.54mm; Mfr# PRPC004DAAN-RC
R1: 1M; R_Axial_DIN0207_L6.3mm_D2.5mm_P10.16mm_Horizontal; Mfr# RNF14FTD1M00
R2: 1k; R_Axial_DIN0207_L6.3mm_D2.5mm_P10.16mm_Horizontal; Mfr# RNF14FTD1K00
R3, R4, R5, R6, R13, R14: 10K; R_Axial_DIN0207_L6.3mm_D2.5mm_P10.16mm_Horizontal; Mfr# RNF14FTD10K0
R7: 220; R_Axial_DIN0204_L3.6mm_D1.6mm_P2.54mm_Vertical; Mfr# RNF14FTD221R
R8, R9: 27; R_Axial_DIN0204_L3.6mm_D1.6mm_P2.54mm_Vertical; Mfr# RNF14FTD27R4
R10, R11: 330; R_Axial_DIN0204_L3.6mm_D1.6mm_P2.54mm_Vertical; Mfr# RNF14FTD330R
R12: 2K; R_Axial_DIN0207_L6.3mm_D2.5mm_P10.16mm_Horizontal; Mfr# RNF14FTD10K0
SW1: RESET; SW_PUSH_6mm_h5mm; Mfr# MJTP1230
SW2: POWER SWITCH; SW_DIP_x1_W7.62mm_Slide; Mfr# BD01
U1: 74LS32; DIP-14_W7.62mm
U2: 74HCT04; DIP-14_W7.62mm; Mfr# 74HCT04
U3: Z80CPU; DIP-40_W15.24mm; Mfr# Z84C0008PEG
U4: 74LS138; DIP-16_W7.62mm; Mfr# SN74LS138N
U5: Z84C40; DIP-40_W15.24mm; Mfr# Z84C4208PEG
U6: FT230XS-U; TSSOP-16_4.4x5mm_Pitch0.65mm; Mfr# FT230XS-U
U7: 74LS92; DIP-14_W7.62mm; Mfr# 74LS92
Y1: 7.3728Mhz; Crystal_SMD_SeikoEpson_MC405-2pin_9.6x4.1mm_HandSoldering; Mfr# ECS-73-20-5PX-TR

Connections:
/A0: IC2.10 (A0), IC3.10 (A0), J1.3, U2.9, U3.30 (A0)
/A1: IC2.9 (A1), IC3.9 (A1), J1.4, U3.31 (A1), U5.34 (B/~A)
/A2: IC2.8 (A2), IC3.8 (A2), J1.5, U3.32 (A2), U4.1 (A0)
/A3: IC2.7 (A3), IC3.7 (A3), J1.6, U3.33 (A3), U4.2 (A1)
/A4: IC2.6 (A4), IC3.6 (A4), J1.7, U3.34 (A4), U4.3 (A2)
/A5: IC2.5 (A5), IC3.5 (A5), J1.8, U3.35 (A5), U4.4 (E1)
/A6: IC2.4 (A6), IC3.4 (A6), J1.9, U3.36 (A6), U4.5 (E2)
/A7: IC2.3 (A7), IC3.3 (A7), J1.10, U2.11, U3.37 (A7)
/A8: IC2.25 (A8), IC3.25 (A8), J1.11, U3.38 (A8)
/A9: IC2.24 (A9), IC3.24 (A9), J1.12, U3.39 (A9)
/A10: IC2.21 (A10), IC3.21 (A10), J1.13, U3.40 (A10)
/A11: IC2.23 (A11), IC3.23 (A11), J1.14, U3.1 (A11)
/A12: IC2.2 (A12), IC3.2 (A12), J1.15, U3.2 (A12)
/A13: IC2.26 (NC/A13), IC3.26 (A13), J1.16, U3.3 (A13)
/A14: IC2.1 (NC/A14), IC3.1 (A14), J1.17, U3.4 (A14)
/A15: J1.18, U1.1, U3.5 (A15)
/CLK_01: J6.4, U7.1 (CP1..3), U7.12 (Q0)
/CLK_02: J6.6, U7.9 (Q2)
/CLK_03: J6.8, U7.8 (Q3)
/D0: IC2.11 (I/O0), IC3.11 (DQ0), J1.19, U3.14 (D0), U5.40 (D0)
/D1: IC2.12 (I/O1), IC3.12 (DQ1), J1.20, U3.15 (D1), U5.1 (D1)
/D2: IC2.13 (I/O2), IC3.13 (DQ2), J1.21, U3.12 (D2), U5.39 (D2)
/D3: IC2.15 (I/O3), IC3.15 (DQ3), J1.22, U3.8 (D3), U5.2 (D3)
/D4: IC2.16 (I/O4), IC3.16 (DQ4), J1.23, U3.7 (D4), U5.38 (D4)
/D5: IC2.17 (I/O5), IC3.17 (DQ5), J1.24, U3.9 (D5), U5.3 (D5)
/D6: IC2.18 (I/O6), IC3.18 (DQ6), J1.25, U3.10 (D6), U5.37 (D6)
/D7: IC2.19 (I/O7), IC3.19 (DQ7), J1.26, U3.13 (D7), U5.4 (D7)
/IEI: J4.2, J4.4, J4.6, J4.8, J4.10, U5.6 (IEI)
/INT_0: J2.4, U5.7 (IEO)
/INT_1: J2.5, J4.3
/INT_2: J2.6, J4.5
/INT_3: J2.7, J4.7
/INT_4: J2.8, J4.9
/MEM_EXT: J2.1, R12.1, U1.2, U1.5
/RAM_SEL: IC3.20 (~CE), U1.6
/ROM_SEL: IC2.20 (~CE), U1.3, U2.5
/Rx: U5.15 (TxDA), U6.4 (RXD)
/RxB: J2.2, U5.29 (RxDB)
/SIO2_SEL: U4.15 (O0), U5.35 (~CE)
/SIOB_CLK: J6.1, J6.3, J6.5, J6.7, U5.27 (~TxCB), U5.28 (~RxCB)
/Tx: U5.12 (RxDA), U6.1 (TXD)
/TxB: J2.3, U5.26 (TxDB)
/~BUSACK: J1.40, R13.2, U3.23 (~BUSACK~)
/~BUSRQ: J1.39, R14.2, U3.25 (~BUSRQ~)
/~CLK: J1.28, J6.2, U2.4, U3.6 (~CLK~), U5.13 (~RxCA), U5.14 (~TxCA), U5.20 (CLK), U7.14 (CP0)
/~CTS: U5.17 (~RTSA), U6.6 (~CTS)
/~HALT: J1.34, U3.18 (~HALT~)
/~INT: J1.30, R5.2, U3.16 (~INT~), U5.5 (~INT)
/~IORQ: J1.38, U3.20 (~IORQ~), U5.36 (~IORQ)
/~M1: J1.31, U3.27 (~M1~), U5.8 (~M1)
/~MRD: IC2.22 (~OE), IC3.22 (~OE), U1.8
/~MREQ: J1.37, U1.9, U1.12, U3.19 (~MREQ~)
/~MWR: IC2.27 (~WE), IC3.27 (~WE), U1.11
/~NMI: J1.29, R3.2, U3.17 (~NMI~)
/~RD: J1.35, U1.10, U3.21 (~RD~), U5.32 (~RD)
/~RESET: IC1.2 (~RESET), J1.27, R4.2, SW1.2, U3.26 (~RESET~), U5.21 (~RESET), U6.11 (~RESET)
/~RFSH: J1.32, U3.28 (~RFSH~)
/~RTS: U5.18 (~CTSA), U6.2 (~RTS)
/~WAIT: J1.33, R6.2, U3.24 (~WAIT~), U5.10 (~W~/~RDYA~), U5.30 (~W~/~RDYB)
/~WR: J1.36, U1.13, U3.22 (~WR~)
GND: C1.2, C2.2, C3.2, C4.2, C5.2, C6.2, C7.2, C8.2, C9.2, C10.2, C11.2, C12.2, D1.1 (K), IC1.1 (GND), IC2.14 (GND), IC3.14 (GND), J1.1, J5.5 (GND), J5.6 (Shield), R12.2, SW1.1, U1.7 (GND), U2.7 (GND), U2.13, U3.29 (GND), U4.8 (GND), U5.19 (~DCDA), U5.22 (~DCDB), U5.23 (~CTSB), U5.31 (GND), U6.5 (GND), U6.13 (GND), U7.10 (GND)
unnamed: C1.1, R1.2, U2.1, Y1.1
unnamed: C2.1, R2.1, Y1.2
unnamed: C3.1, R9.2, U6.9 (USBDM)
unnamed: C4.1, R8.2, U6.8 (USBDP)
unnamed: C5.1, U6.3 (VCCIO), U6.10 (3V3OUT)
unnamed: D1.2 (A), R7.1
unnamed: D2.1 (K), U6.14 (CBUS1/~RXLED)
unnamed: D2.2 (A), R10.2
unnamed: D3.1 (K), U6.7 (CBUS2/~TXLED)
unnamed: D3.2 (A), R11.2
unnamed: J5.1 (VBUS), SW2.2
unnamed: J5.2 (D-), R9.1
unnamed: J5.3 (D+), R8.1
unnamed: R1.1, R2.2, U2.2, U2.3
unnamed: U1.4, U2.6
unnamed: U2.8, U5.33 (C/~D)
unnamed: U2.10, U4.6 (E3)
VCC: C6.1, C7.1, C8.1, C9.1, C10.1, C11.1, C12.1, IC1.3 (VCC), IC2.28 (VCC), IC3.28 (VCC), J1.2, J4.1, R3.1, R4.1, R5.1, R6.1, R7.2, R10.1, R11.1, R13.1, R14.1, SW2.1, U1.14 (VCC), U2.14 (VCC), U3.11 (VCC), U4.16 (VCC), U5.9 (VCC), U6.12 (VCC), U7.5 (VCC)

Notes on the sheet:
8kB or 32kB ROM
32kB RAM
00 (J1-2) ÷1 01 (J3-4) ÷2 02 (J5-6) ÷6 03 (J7-8) ÷12
DUAL SERIAL IO DEVICE INTERRUPT 0 (INT_0) DEVICE PORTS 0x00 to 0x03 ================== 0x00: Channel A, Control 0x01: Channel A, Data 0x02: Channel B, Control 0x03: Channel B, Data
Parent interrupt selection Selecting INT_0 (J1-2) as the parent (SELF) means that the current IO device is the first device of the dasy chain.
Stabilization Capacitors
Mounting Holes
Power Led
Powered components and components stabilization
SIO Port A, UART to USB interface
SIO Port B Clock Divider
NOTE: When MEM_EXT is HIGH, the onboard memory is disabled. Otherwise, this pin should be floating.
The ADM803TAKSZ-REEL7 chip is a little package that monitors the power line. When the device is powered, it pulls the ~RESET~ pin low for 240ms then keeps it open for as long as the device is powered. Still need a pull-up resistor to keep ~RESET~ high afterward.
Clock Circuit

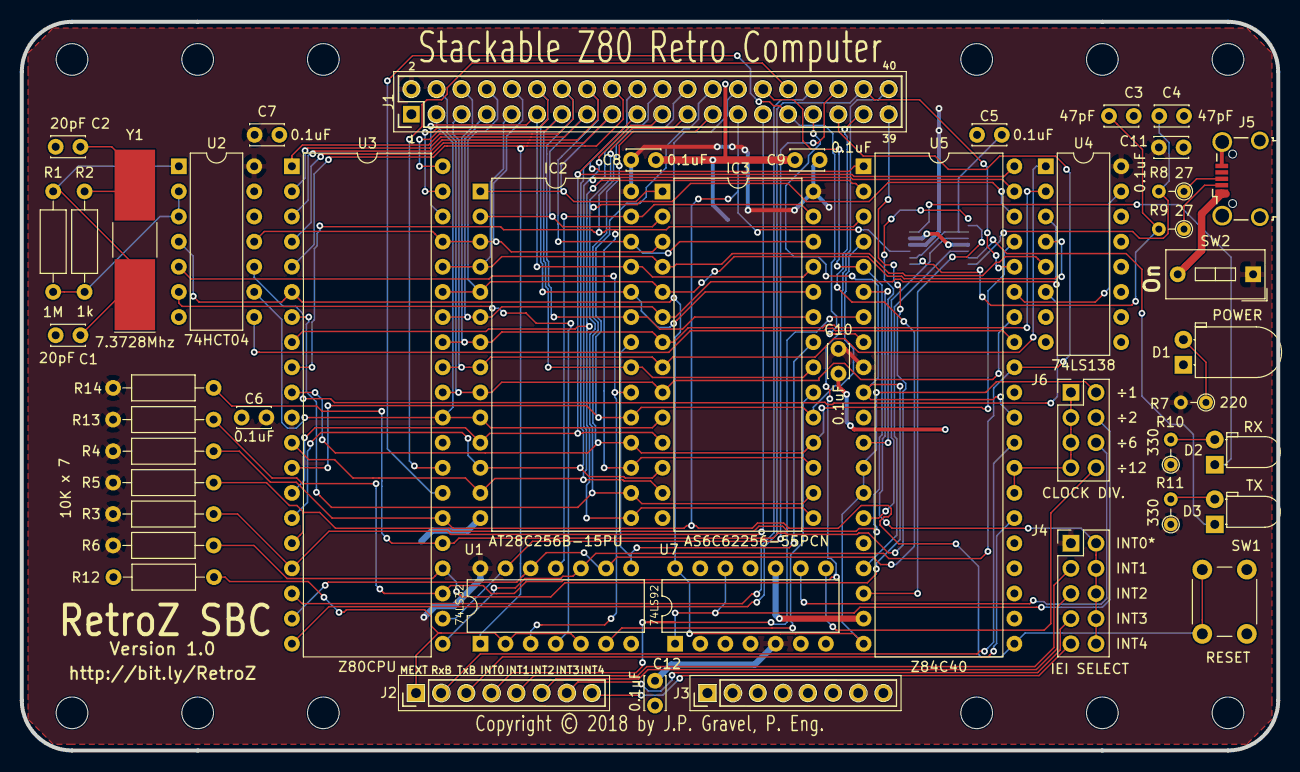
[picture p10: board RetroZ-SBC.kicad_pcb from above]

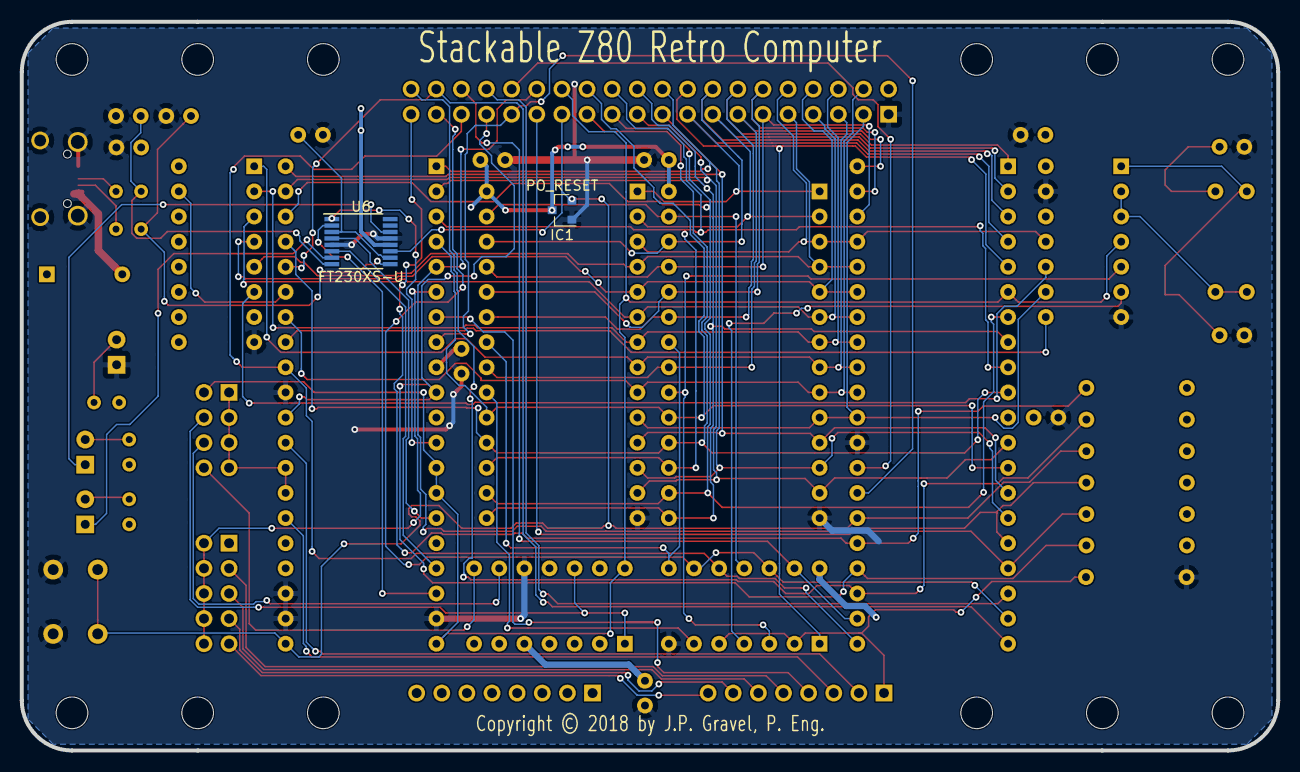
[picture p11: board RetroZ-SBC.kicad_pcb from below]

Board: 2 copper layers, 127.0 x 73.7 mm, 60 parts (2 on the bottom side), 79 nets.

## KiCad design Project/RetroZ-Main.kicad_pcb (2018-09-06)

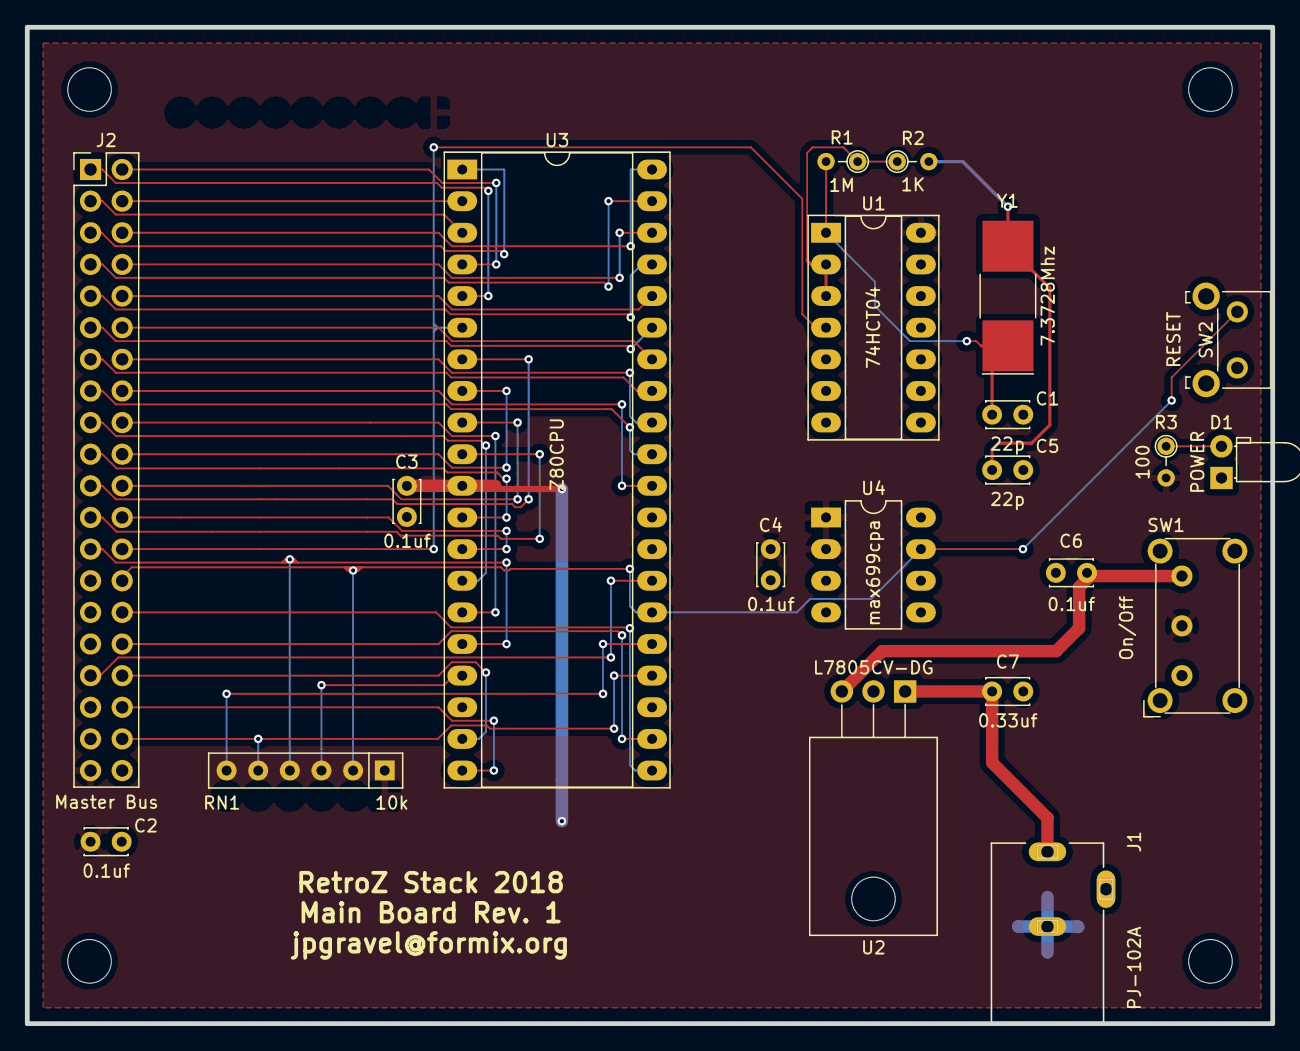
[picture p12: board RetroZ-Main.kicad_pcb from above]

Board: 2 copper layers, 100.0 x 80.0 mm, 21 parts (0 on the bottom side), 43 nets.

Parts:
C1, C5: 22p; C_Disc_D3.4mm_W2.1mm_P2.50mm
C2, C3, C4, C6: 0.1uf; C_Disc_D3.4mm_W2.1mm_P2.50mm
C7: 0.33uf; C_Disc_D3.4mm_W2.1mm_P2.50mm
D1: POWER; LED_D3.0mm_Horizontal_O1.27mm_Z2.0mm
J1: PJ-102A; CUI_PJ-102A
J2: Master Bus; Pin_Header_Straight_2x20_Pitch2.54mm
R1: 1M; R_Axial_DIN0204_L3.6mm_D1.6mm_P2.54mm_Vertical
R2: 1K; R_Axial_DIN0204_L3.6mm_D1.6mm_P2.54mm_Vertical
R3: 100; R_Axial_DIN0204_L3.6mm_D1.6mm_P2.54mm_Vertical
RN1: 10k; R_Array_SIP6
SW1: On/Off; SW_E-Switch_EG1224_SPDT_Angled
SW2: RESET; SW_Tactile_SKHH_Angled
U1: 74HCT04; DIP-14_W7.62mm_Socket_LongPads
U2: L7805CV-DG; TO-220-3_Horizontal
U3: Z80CPU; DIP-40_W15.24mm_Socket_LongPads
U4: max699cpa; DIP-8_W7.62mm_LongPads
Y1: 7.3728Mhz; Crystal_SMD_SeikoEpson_MC405-2pin_9.6x4.1mm

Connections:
/A0: J2.16, U3.30
/A1: J2.15, U3.31
/A2: J2.14, U3.32
/A3: J2.13, U3.33
/A4: J2.12, U3.34
/A5: J2.11, U3.35
/A6: J2.10, U3.36
/A7: J2.9, U3.37
/A8: J2.8, U3.38
/A9: J2.7, U3.39
/A10: J2.6, U3.40
/A11: J2.5, U3.1
/A12: J2.4, U3.2
/A13: J2.3, U3.3
/A14: J2.2, U3.4
/A15: J2.1, U3.5
/D0: J2.17, U3.14
/D1: J2.18, U3.15
/D2: J2.19, U3.12
/D3: J2.20, U3.8
/D4: J2.21, U3.7
/D5: J2.22, U3.9
/D6: J2.23, U3.10
/D7: J2.24, U3.13
CLK: J2.26, U1.4, U3.6
GND: C1.2, C2.2, C3.2, C4.2, C5.2, C6.2, C7.2, D1.1, J1.2, J2.40, SW2.2, U1.7, U2.2, U3.29, U4.3, U4.4, U4.8
unnamed: C1.1, R1.2, U1.1, Y1.1
unnamed: C5.1, R2.2, Y1.2
unnamed: C6.1, SW1.3, U2.3
unnamed: C7.1, J1.1, U2.1
unnamed: D1.2, R3.1
unnamed: R1.1, R2.1, U1.2, U1.3
unnamed: RN1.3, U3.17
unnamed: RN1.6, U3.25
VCC: C2.1, C3.1, C4.1, J2.39, R3.2, RN1.1, SW1.2, U1.14, U3.11, U4.1, U4.2
~INT: J2.25, RN1.4, U3.16
~IORQ: J2.36, U3.20
~M1: J2.33, U3.27
~MREQ: J2.34, U3.19
~RD: J2.30, U3.21
~RESET: J2.28, RN1.2, SW2.1, U3.26, U4.7
~WAIT: J2.38, RN1.5, U3.24
~WR: J2.32, U3.22

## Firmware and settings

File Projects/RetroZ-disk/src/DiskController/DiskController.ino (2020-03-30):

#include <SD.h>


/* Pins */
#define STATUS_LED      8

/* Masks */
#define MASK_MODE       0x3   /* Pins 14, 15 */
#define MASK_READ_OUT   0x4   /* Pin 16 */
#define MASK_WRITE_IN   0x8   /* Pin 17 */
#define MASK_SELECTED   0xF   /* Pin 18 */

/* Registres */
#define REG_CONTROL PORTC
#define REG_DATA    PORTD



/* Modes */
#define MODE_DATA    0
#define MODE_COMMAND 1
#define MODE_STATUS  2  /* Read only */


/* List of statuses */
#define STATUS_OK            0
#define STATUS_BAD_MODE      1
#define STATUS_WRITE_ERROR   2
#define STATUS_SD_INIT_ERROR 3


/********** State of the program **********/

/* result status of the last command */
byte _status;


void setup() {
  // Make sure all pins are high impedence at boot.
  for(int pin = 0; pin < 20; pin++) {
    pinMode(pin, INPUT);
  }

  digitalWrite(STATUS_LED, LOW);
  pinMode(STATUS_LED, INPUT);
  if (!SD.begin(10)) {
    _status = STATUS_SD_INIT_ERROR;
    blink_status(3);
  }
  else {
    _status = STATUS_OK;
    blink_status(2);
  }
}


void loop() {
  bool selected = REG_CONTROL & MASK_SELECTED;
  if (selected) {
    byte mode = REG_CONTROL & MASK_MODE;
    byte data_dir = INPUT;
    if (REG_CONTROL & MASK_READ_OUT) {
      data_dir = OUTPUT;
    }

    switch (mode) {
      case MODE_DATA:
        break;

      case MODE_COMMAND:
        break;

      case MODE_STATUS:
        if (data_dir == INPUT) {
          // external device cannot write into _status.
          _status = STATUS_WRITE_ERROR;
          return;
        }
        if (data_dir == OUTPUT)
          REG_DATA = _status;
          _status++; // TEST INITIAL!!!
        break;

      default:
        _status = STATUS_BAD_MODE;
    }

    setDataDir(data_dir);
  }
  else {
    // Set input to high impedance when not selected.
    setDataDir(INPUT);
  }
}


/* Sets the data bus direction (INPUT or OUTPUT) */
void setDataDir(byte value) {
  if (value == INPUT) {
    DDRD = B00000000;
  }
  else {
    DDRD = B11111111;
  }
}


void blink_status(byte count) {
  for (int i = 0; i < count; i++) {
    digitalWrite(STATUS_LED, HIGH);
    delay(125);
    digitalWrite(STATUS_LED, LOW);
    delay(125);
  }
}

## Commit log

2018-08-18 first commit... maybe?
    [RetroZ-SBC.sch]
2018-08-18 moved to another design with Serial Basic module
    [RetroZ-SBC.sch]
2018-08-20 deleted no reset btn comment
    [RetroZ-SBC.sch]
2018-08-21 initial layout
    [RetroZ-SBC.kicad_pcb, RetroZ-SBC.sch]
2018-08-21 started the physical layout
    [RetroZ-SBC.kicad_pcb]
2018-08-22 started the layout
    [RetroZ-SBC.kicad_pcb, RetroZ-SBC.sch]
2018-08-22 added some data wires
    [RetroZ-SBC.kicad_pcb, RetroZ-SBC.sch]
2018-08-23 fixed the ratnest!
    [RetroZ-SBC.kicad_pcb]
2018-08-25 current state
    [RetroZ-SBC.kicad_pcb]
2018-08-30 new master bus design
    [RetroZ-SBC.kicad_pcb, RetroZ-SBC.sch]
2018-09-03 removed ctc
    [RetroZ-SBC.kicad_pcb, RetroZ-SBC.sch]
2018-09-03 removed all '-SBC' values
    [RetroZ.kicad_pcb, RetroZ.sch]
2018-09-03 splitted main and memory units
    [RetroZ-Main.sch, RetroZ-Memory.sch]
2018-09-03 remade the main board
    [RetroZ-Main.kicad_pcb, RetroZ-Main.sch]
2018-09-03 finished main board
    [RetroZ-Main.kicad_pcb]
2018-09-06 memory board halfway
    [RetroZ-Main.kicad_pcb, RetroZ-Main.sch, RetroZ-Memory.kicad_pcb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]
2018-09-09 restructuration du dossier de projet
    [RetroZ-Main.kicad_pcb, RetroZ-Main.sch, RetroZ-Memory.kicad_pcb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]
2018-09-22 added usb to serial with an FT230XS-U chip
    [RetroZ-Main.kicad_pcb, RetroZ-Main.sch, RetroZ-Memory.kicad_pcb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]
2018-09-22 in the process of updating the bus and fixing memory board mega-issue!
    [RetroZ-Memory.kicad_pcb, RetroZ-Memory.sch]
2018-09-22 fixed Processor Board
    [RetroZ-Main.kicad_pcb, RetroZ-Main.sch, RetroZ-Memory.sch]
2018-10-02 terminated the memory board
    [RetroZ-Memory.kicad_pcb, RetroZ-Memory.sch]
2018-10-02 fixed the bus and removed RxTx from the ctc-sio2 board
    [RetroZ-Memory.sch, SIO2-CTC.kicad_pcb, SIO2-CTC.sch]
2018-10-05 finished sio2 board
    [RetroZ-Memory.kicad_pcb, SIO2-CTC.kicad_pcb, SIO2-CTC.sch]
2018-10-14 fixed a bunch of issues with the main board and some on the memory board
    [RetroZ-Main.kicad_pcb, RetroZ-Main.sch, RetroZ-Memory.kicad_pcb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]
2018-10-16 changed power-on reser chip
    [RetroZ-Main.kicad_pcb, RetroZ-Main.sch]
2018-10-17 fixing memory access time
    [RetroZ-Main.kicad_pcb, RetroZ-Memory.kicad_pcb, RetroZ-Memory.sch]
2018-10-17 added quad nor to accelerate memory chip select decoding
    [RetroZ-Memory.kicad_pcb, RetroZ-Memory.sch]
2018-10-17 simplified schematic
    [RetroZ-Memory.kicad_pcb, RetroZ-Memory.sch]
2018-10-17 adjusted configuration for JLCPCB plotting
    [RetroZ-Main.kicad_pcb, RetroZ-Main.sch, RetroZ-Memory.kicad_pcb]
2018-10-30 completed Main BOM
    [Main.xlsx, RetroZ-Main.sch, RetroZ-Memory.kicad_pcb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]
2018-11-11 added BOMs
    [Main.xlsx, Memory.xlsx, RetroZ-Main.sch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]
2018-11-16 updated BOM and changed on capacitor
    [Main.xlsx, Memory.xlsx, RetroZ-Main.sch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]
2018-12-31 SBC First commit!
    [Main.xlsx, Memory.xlsx, RetroZ-Main.kicad_pcb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]
2019-01-03 added a dip switch to toggle the computer power
    [RetroZ-SBC.kicad_pcb, RetroZ-SBC.sch]
2019-01-06 updated readme.md and some schematic texts
    [RetroZ-SBC.kicad_pcb, RetroZ-SBC.sch]
2019-01-06 moved some high speed signals traces away from other traces
    [RetroZ-SBC.kicad_pcb, RetroZ-SBC.sch]
2019-01-06 added stacking header notice
    [RetroZ-SBC.kicad_pcb]
2019-01-10 increased the width of a VCC trace
    [RetroZ-SBC.kicad_pcb]
2019-01-15 added pull-up resistors and comments
    [RetroZ-SBC.sch]
2019-01-16 moved interrupts to user port A
    [RetroZ-SBC.sch]
2019-01-20 added missing pull-ups and changed git status
    [RetroZ-SBC.kicad_pcb, RetroZ-SBC.sch]
2019-01-20 updated a few lables
    [RetroZ-SBC.kicad_pcb]
2019-01-20 added an url to the board
    [RetroZ-SBC.kicad_pcb]
2019-01-26 added BOM information
    [RetroZ-SBC-BOM.ods, RetroZ-SBC.sch]
2019-01-26 added the bom to README
    [RetroZ-SBC-BOM.ods]
2019-01-26 added the desctiption to the BOM
2019-02-06 fixed the 1M/1k resistor inversion issue!
    [RetroZ-SBC.kicad_pcb]
2019-03-03 added print space test
2019-06-12 added the S80 Library
    [RetroZ-SBC.sch, S80 Template.kicad_pcb, S80-Library.kicad_pcb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]
2019-08-09 added the template
    [RetroZ-SBC-BOM-2.ods, RetroZ-SBC.sch, S80 Template.kicad_pcb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]
2019-08-09 deleted some files
    [S80 Template.kicad_pcb]
2019-08-12 Fixed the template issue
    [S80 Template.kicad_pcb]
2019-08-12 renamed the template file
    [S80-Template.kicad_pcb]
2019-08-12 created the RetroZ-RAM24K extension
    [RetroZ-RAM24K.kicad_pcb, RetroZ-RAM24K.sch]
2019-08-13 adding footprints...
    [RetroZ-RAM24K.sch]
2020-01-13 added the RetroZ-disk
    [RetroZ-disk.kicad_pcb, RetroZ-disk.sch]
2020-01-30 Created the schematic
    [RetroZ-SBC.sch, RetroZ-disk.kicad_pcb, RetroZ-disk.sch]
2020-03-06 RetroZ disk design done
    [RetroZ-disk.kicad_pcb]
2020-03-12 added interrupt signal
    [RetroZ-disk.kicad_pcb, RetroZ-disk.sch]
2020-03-12 fixed interrupt ack processing
    [RetroZ-disk.kicad_pcb, RetroZ-disk.sch]
2020-03-27 removed interrupt management, added arduino code
    [RetroZ-disk.kicad_pcb, RetroZ-disk.sch]
2020-03-29 commit a hugge change set
    [RetroZ-RAM24K.kicad_pcb, RetroZ-RAM24K.sch, RetroZ-SBC.kicad_pcb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]
2020-03-29 fixed typo
    [RetroZ-disk.kicad_pcb, RetroZ-disk.sch]

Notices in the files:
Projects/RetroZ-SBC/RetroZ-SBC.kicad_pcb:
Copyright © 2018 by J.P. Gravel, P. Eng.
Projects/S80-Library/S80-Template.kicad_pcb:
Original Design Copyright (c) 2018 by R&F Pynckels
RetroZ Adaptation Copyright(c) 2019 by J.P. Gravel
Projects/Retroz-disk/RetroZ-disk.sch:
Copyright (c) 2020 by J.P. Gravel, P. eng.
